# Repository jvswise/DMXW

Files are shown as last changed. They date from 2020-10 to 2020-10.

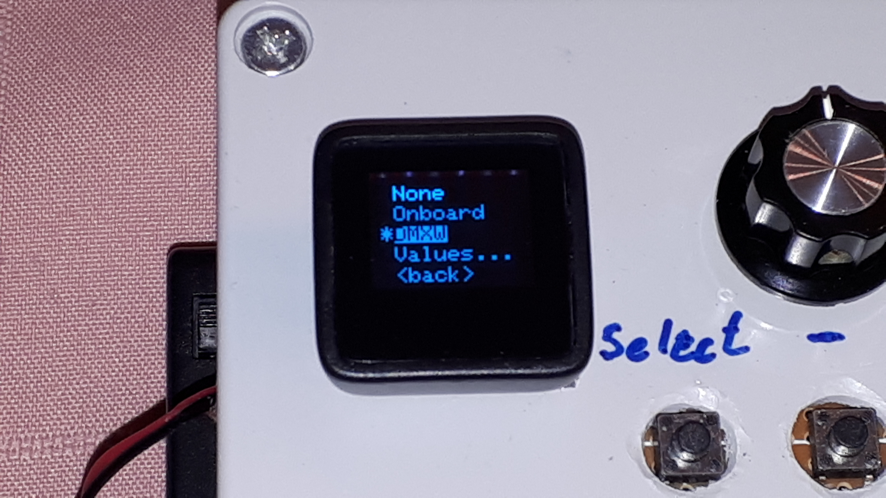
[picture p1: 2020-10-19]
Documentation/DMXW Tester Documents/Photos/Display - Outputs.jpg

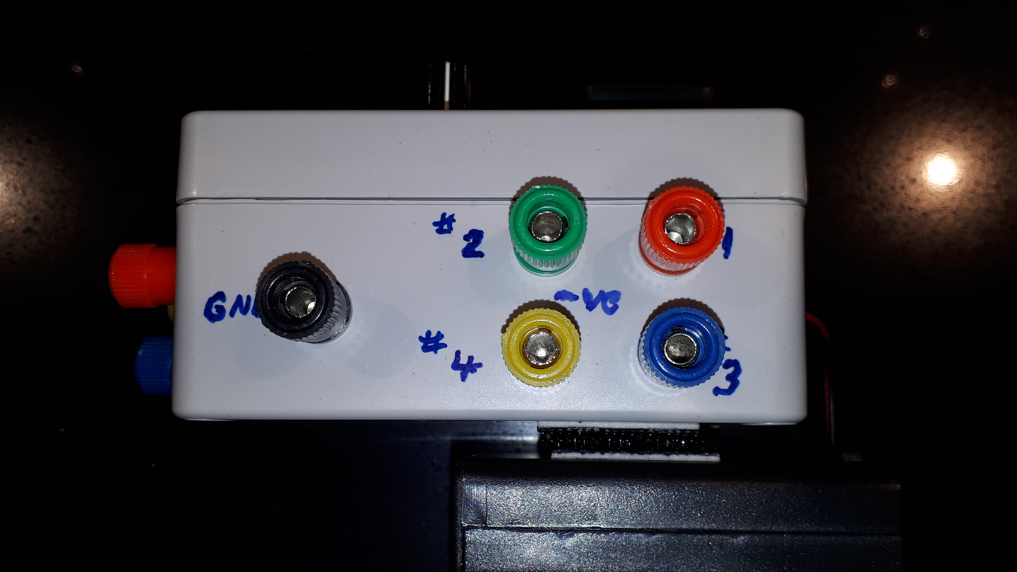
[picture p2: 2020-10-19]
Documentation/DMXW Tester Documents/Photos/Channels 1-4 connections.jpg

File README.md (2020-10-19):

# DMXW
DMX-512 wireless gateway to networked Moteino RFM69 (Arduino compatible) based slave devices suitable for running battery operated stage effects up to 300 metres from the gateway.

The gateway allows DMX-512 channels to be be redistributed to low-cost, customizable, battery-operated Moteino based slave nodes. Slaves have 4 analog (PWM) channels that can drive several amps each at 5 -12 Vdc. They have an additional two digital channels. 

There is prototype code, schematics, PCB files, and user manuals:
  - A configurable DMX-512 to DMXW gateway with optional manaul override
    controls (joystick, toggle switches, and potentiometers).
  - A generic remote slave node.
  - A specialized remote slave node for driving an LED pixel strip.
  - A test unit for either remote testing independent of a DMX-512 bus or
    for onboard testing of electronics that are to be connected to a generic
    or pixel strip node.

Folders:
  Arduino_sketches:
    - Arduino sketches for gateway, generic and remote slave nodes, and
      test unit.

  Documentation:
    - User manuals, schematics, PCB files, construction guides.

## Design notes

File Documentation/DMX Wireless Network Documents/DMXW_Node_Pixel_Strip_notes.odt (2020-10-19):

# Configuring a DMXW Node for Addressable LED Pixel Strips

The node must be running the DMXW_Node_Pixel_Strip firmware (rather than the generic DMXW_Wireless_Node firmware). This firmware only supports control of a single addressable LED strip. It is not programmed to support multiple strips, nor generic analog and digital outputs.

By default the remote node is configured to control the addressable LED strip using Moteino digital output 4 (Digital low power #1 on the J7 connector in schematic “DMXW_Driver_Board”, rev 1.1, dated 2014-07-16). To change this to a different pin, use console command “ledCtrl”

The LED strip needs to be configured on the remote node

- The console command is “led”
- LED strip length: the number of ganged tricolour LEDs (pixels)
  - 12 Vdc strips gang together three tricolour LEDs per “pixel”
  - 5 Vdc strips have one tricolour LED per pixels
- Control frequency: usually 800 Khz
- LED colour wiring order: usually GRB (?)

After changing either of the above, use console command “save” to save the configuration changes to EEPROM, and power cycle the node for the changes to take effect.

# Programming Effects:

The node defines a number of ports with pre-defined functions. Port can be mapped to arbitrary DMXW channels which can, in turn, be assigned to arbitrary DMX-512 channels.

The node's port assignments are shown in the table below.

Port # | Function
1 | Delay (in milliseconds): 0 = all LEDs off; 255 = hold current effect settings The hold setting can be used to hold an effect while other ports are changed (e.g. Manually) in advance to selecting new effect settings when Delay is taken out of hold mode. Not all effects obey delay settings in the range 1 – 254 (refer to individual effect setting in the following table)
2 | Effect: Selects the type of effect to run. To aid in manual selection via (noisy) potentiometers, each effect occupies a decade of values (refer to the following table).
3 | Parameter Arg1 | The various types of effect take varying numbers of parameters that are specified via these ports. (Refer to the following table.)
4 | Parameter Arg2
5 | Parameter Arg3
6 | Parameter Arg4
7 | Parameter Arg5
8 | Parameter Arg6
9 | Parameter Arg7

Table 1: Port Assignment Summary

The various types of effects are summarized in the following table.

Effect Name | Effect Value Range | Description | Parameters
Colour Wipe | 10 - 19 | End-to-end wipe from previous colour (black is initial colour) to newly selected colour. | Arg1 (red) Arg2 (green) Arg3 (blue) Affected by the Delay setting.
Rainbow | 20 - 29 | Wipe in a rainbow pattern. | Only affected by the Delay setting.
Rainbow Cycle | 30 - 39 | Lengthwise rolling rainbow pattern. | Only affected by the Delay setting.
Theatre Chase | 40 - 49 | Theatre marquis-style motion. | Arg1 (red) Arg2 (green) Arg3 (blue) Affected by the Delay setting.
Theatre Chase Rainbow | 50 - 59 | Theatre marquis-style motion with gradual colour change spanning the rainbow. | Only affected by the Delay setting.
Water and Embers | 60 - 69 | Undulating colour variation effect that can be used to simulate wavy waters or glowing embers. | Arg1 (red range low setting) Arg2 (green range low setting) Arg3 (blue range low setting) Arg4 (red range high setting) Arg5 (green range high setting) Arg6 (blue range high setting) Arg7 (rate of colour changes) Affected by the Delay setting. Suggested settings: For wavy waters: Red range: 0 – 0 Green range: 140 – 170 Blue range: 50 – 60 Depth: 25 Delay: 3 For glowing embers: Red range: 100 - 255 Green range: 20 – 30 Blue range: 0 – 3 Depth: 5 Delay: 3
Twinkle | 70 - 79 | Bright white twinkles on a selected background colour. | Arg1 (red) Arg2 (green) Arg3 (blue) Arg4 (min delay x 10 between twinkles) Arg5 (max delay x 10 between twinkles) Arg6 (max number of pixels that can twinkle simultaneously) Arg7 (hold time for a twinkle, in milliseconds) (The normal Delay range settings have no affect.)

Table 2: Effects Settings Summary

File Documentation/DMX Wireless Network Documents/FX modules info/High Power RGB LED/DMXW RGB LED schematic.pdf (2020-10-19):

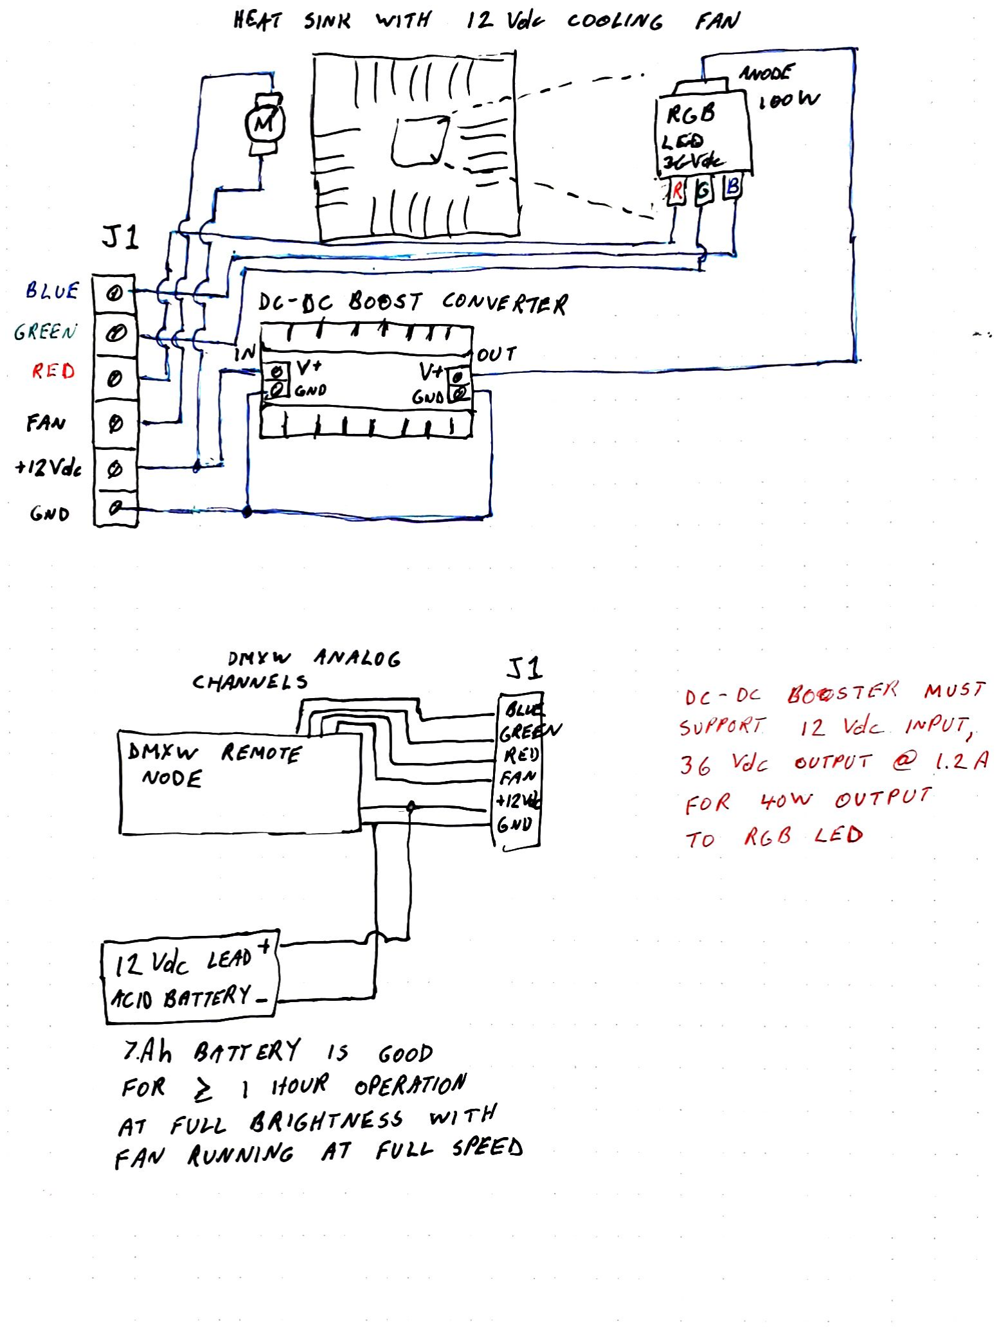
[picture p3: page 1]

HEAT SINK WITH

### 12 Volc COOLING

FAN
Illlll
WORE
11ooh
RGB
Taarde
ORG
J1
G
BLUE
DC-DC BOOST CONVERTER
GREEN
RED
YOUT
tolGND
Grote
+12Vdc Lo
GND
ANALOG
DMYW
CHANNELS
GREEN
DMXW REMOTE
NODE
RED
DC-DC BOOSTER MUST
SUPPORT 12 Voc. INPUT,
36 Volc OUTPUT @ 1.
2A
FOR 40W OUTPUT
TO RGB LED
FAN
+12 vold
GND
[ 12 volc LEAD *
ACIO BATTERY
7.Ah BATTERY IS GOOD
FOR Z 1 HOUR OPERATION

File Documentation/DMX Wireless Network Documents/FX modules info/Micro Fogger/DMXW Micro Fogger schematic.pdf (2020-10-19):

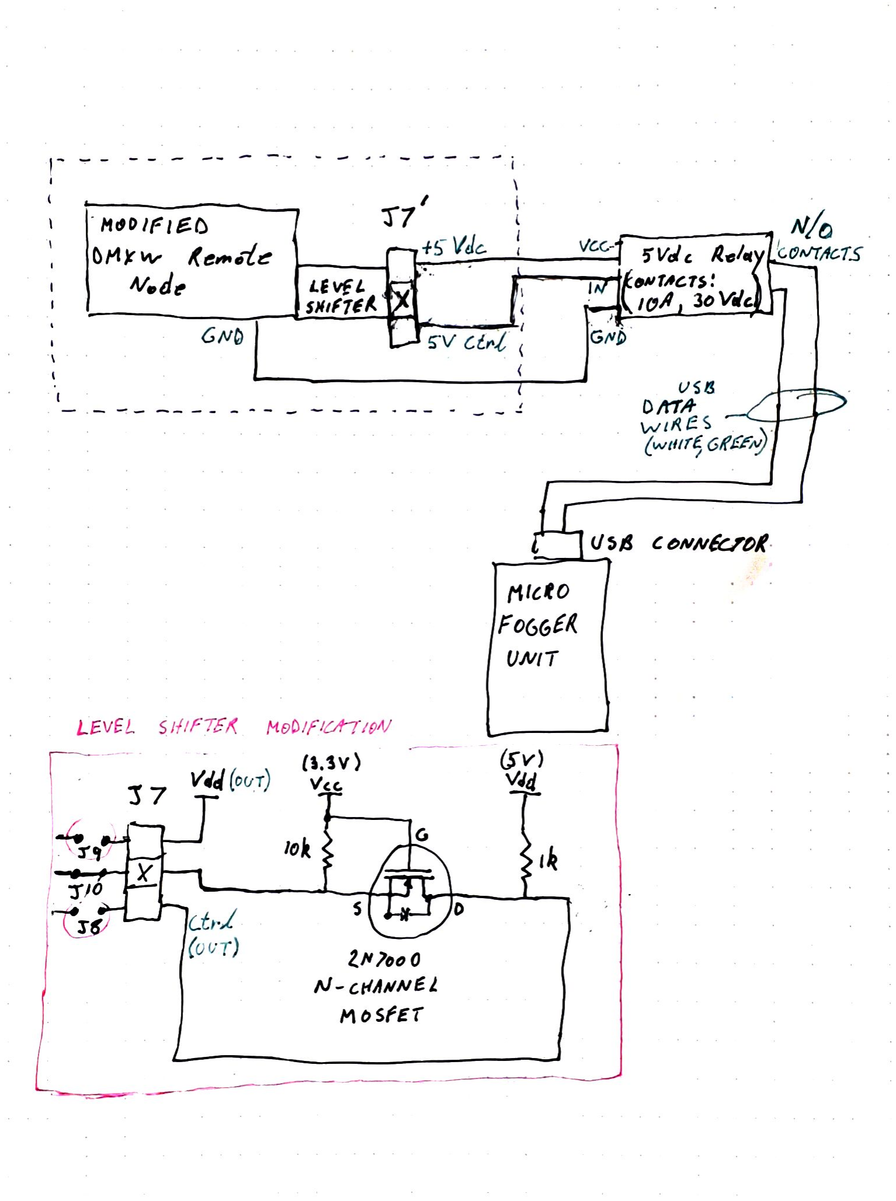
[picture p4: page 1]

MODIFIED
lomow Remote
: 57
my to kolc
LEVEL
I SHIFTER
!
- Node
Vect
- N/a
5Vdc Relay / CONTACTS
wtKONTACTS:
LIOA 30 Vich
C
GNO
GND
USB
DATA
WIRES -
(WHITE, GREEN)
USB CONNECTOR
MICRO
FOGGER
UNIT
LEVEL
SHIFTER
MODIFICATION
Irel
- VCC
Jy vold (out) (3.3v)
1
lok 3
JIÓ
st
thatod

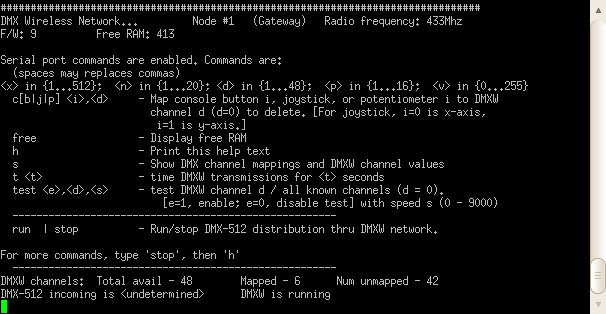
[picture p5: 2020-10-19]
Documentation/DMX Wireless Network Documents/Diagrams/Screenshots/Screenshot--dev-ttyUSB0 - PuTTY.png

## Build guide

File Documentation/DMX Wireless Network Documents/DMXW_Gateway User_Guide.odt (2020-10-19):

DMX-512 Wireless Distribution
Gateway User Guide

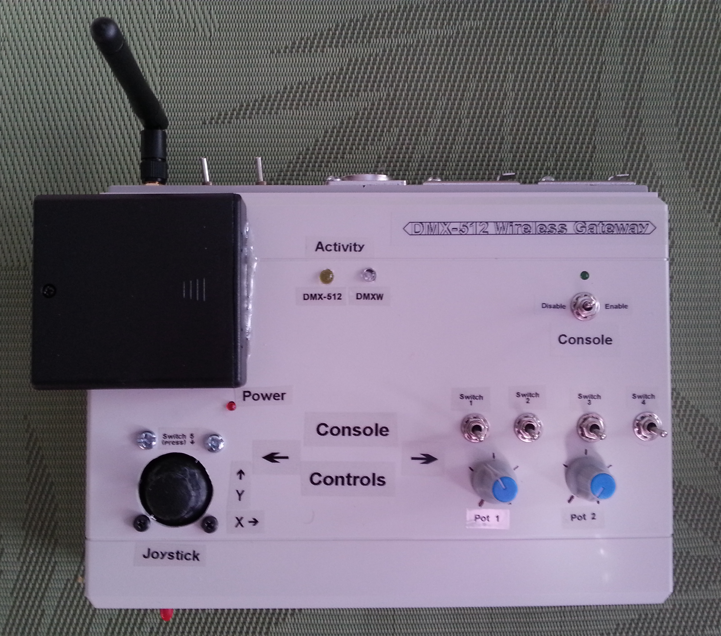
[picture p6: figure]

John van Schouwen

2014

# Introduction

## Overview

DMX-512 is an electrical and data communications standard commonly used to control stage lighting (http://en.wikipedia.org/wiki/Stage_lighting) and effects. It defines up to 512 channels of data, each intended to control a lighting fixture or an aspect of a lighting fixture (e.g. lighting fixture rotation, and lighting element brightness).[^1]

The DMX Wireless Distribution Gateway (or DMXW Gateway) has the capability to redistribute DMX-512 lighting control channels to (usually battery-powered) wireless remote DMXW receiver nodes that are connected to lighting fixtures, motors, actuators, etc.[^2] The gateway extracts up to 48 selected channels from a wired DMX-512 bus and redistributes them to up to 48 output ports located at up to 19 uniquely numbered remote DMXW nodes[^3],[^4]. Using a computer running Windows or Linux, the user can configure the DMX-512 channels to be redistributed. Various test functions are also available via this Config Port.

The gateway also houses Console Controls (switches, potentiometers, and a 2-axis joystick with push-button) that can be assigned to DMXW channels and can override the DMX-512 channels to which they are assigned.

## Features

The following are the DMXW GW features:

- Wireless redistribution (using the DMXW protocol) of up to 48 configurable DMX-512 channels onto DMXW channels.
- Support for up to 19 uniquely numbered remote DMXW wireless receiver nodes
- remote nodes may be cloned
- 433 MHz radio with range > 150 metres for DMXW distribution.
- Capability for fully mobile, standalone, manual, wireless control of up to 9 remote devices connected to one or more remote DMXW receiver nodes.
- Configurable manual console controls that can be used to override up to 9 DMXW channels:
- 4 toggle switches for on/off control (DMX-512 values 0 (off) or 255 (on))
- 2 potentiometers for dimming control
- 1 two-axis, spring-loaded joystick for dimming control
- 1 momentary contact joystick push-button for on/off control
- Console Control enable/disable switch and status indicator
- USB Configuration Port
- 9600 baud, 8-bit data, no parity, 1 stop bit
- Configuration port enable/disable switch
- Dual power option:
- 4 x AA battery pack, or
- 6 – 12 V dc, 200 mA wall adaptor using a 1/8” headphone jack (negative tip)
- DMX-512 and DMXW activity indicators
- DMX-512 bus connectivity:
- 5-pin male, 5-pin female, and 3-pin female XLR connectors for connecting to a DMX-512 bus
- unused connectors can be used for relaying the bus to additional DMX-512 devices
- DMX-512 data line polarity reversal switch (reserves the signal polarities on XLR pins 2 and 3)
- DMX-512 termination resistor (120 Ω) selector switch
- Programming Port for upgrading the gateway's firmware
- USB-to-FTDI adaptor required
- Gateway is programmed from the freely available Arduino programming environment
- Operating Mode switch selects either normal operating mode or firmware programming mode
- Freely available, open source software and development environment
- The gateway's firmware is open source Arduino code
- DMXW remote wireless receiver nodes use Arduino boards and RFM69W (433 MHz) radio modules programmed with open source Arduino code
- Assembled Arduino/radio boards (Moteino boards) can be purchased at http://www.lowpowerlab.com/shop for about $21 USD (as of March, 2014)
- Nodes will require some knowledge of electronics and construction of external circuitry in order to interface the board with output devices (such as LED’s, incandescent lamps, motors, actuators, etc.)

## Gateway Layout

Figure 1 Shows the main operating controls: the console controls and DMX activity indicators.

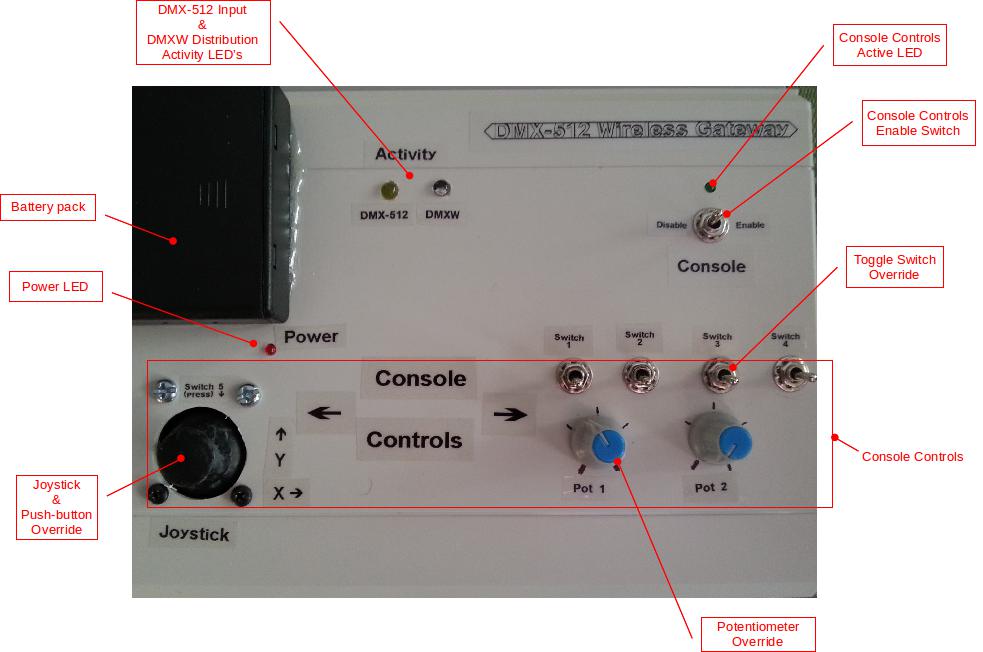
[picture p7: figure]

Figure 1: Top View

Figure 2 Shows the DMX-512 bus connectors and controls and the antenna located at the rear of the DMXW Gateway.

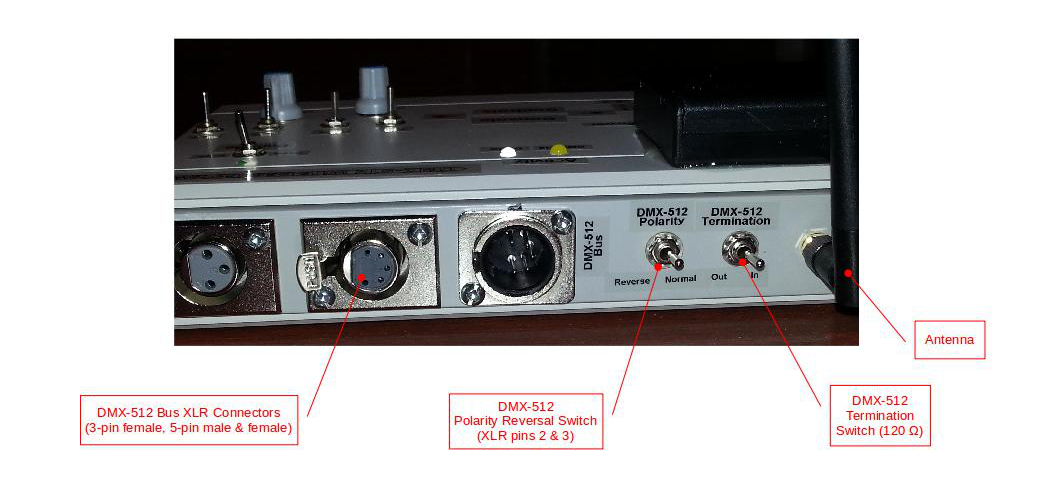
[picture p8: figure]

Figure 2: Rear View

Figure 3 Shows the DMXW Gateway's front panel containing the power switch and the configuration and programming connectors and controls.

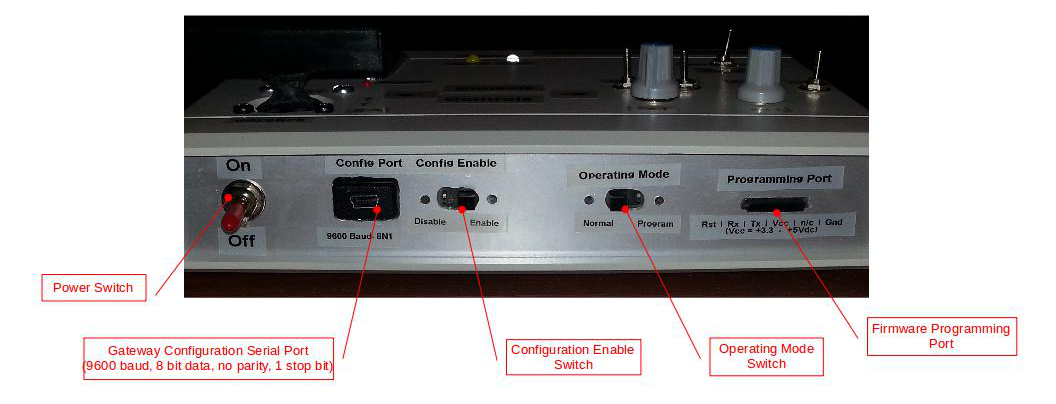
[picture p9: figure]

Figure 3: Front View

Figure 4 Shows the power sources located at the left side of the DMXW Gateway.

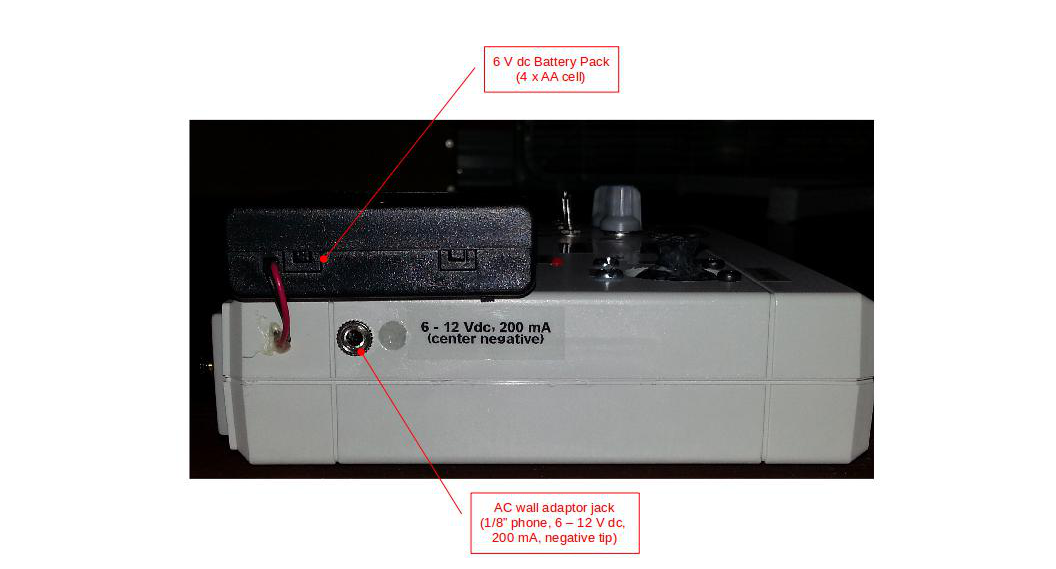
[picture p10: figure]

Figure 4: Left Side View

# Connecting the DMXW Gateway

## Connecting to a DMX-512 Bus

The DMXW Gateway can operate as either a standalone controller (using only the console controls) or connected to a DMX-512 bus for redistribution of selected channels using the DMXW wireless protocol. Referring to Figure 5, when connecting the DMXW Gateway to a DMX-512 bus, it may be connected as either an intermediate node (as shown in the figure) or as a terminating node (e.g. if DMX-512 Device #3 was disconnected).

It is often necessary for the last node on the bus to add a 120 Ω terminating resistor across the two DMX-512 data lines. If this is necessary set the DMX-512 Termination switch to the “In” position; otherwise set it to the “Out” position.

With the DMX-512 Polarity switch set to the “Normal” position, connect the DMXW Gateway to the DMX-512 bus and turn on power to the gateway. Ensure that the Power LED is lit. Make sure that the lighting desk is running DMX-512 data thru the bus. The DMX-512 Activity LED should pulsate to indicate that it is correctly receiving DMX-512 data. If the LED doesn't glow, toggle the DMX-512 Polarity switch to the “Reverse” position. If the DMX-512 Activity LED still doesn't glow, check the DMX-512 bus connections and cables, and double check that data is being transmitted by the lighting desk.

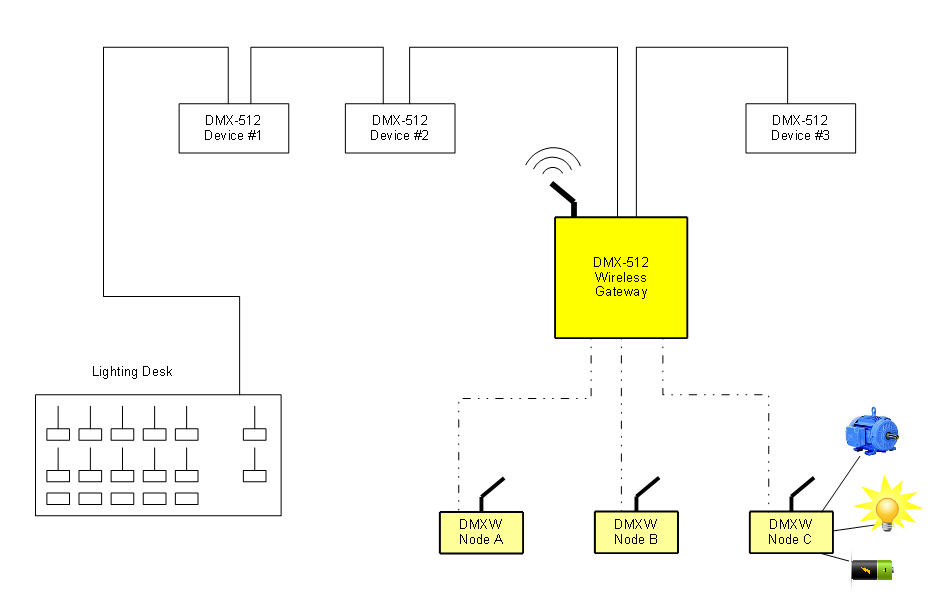
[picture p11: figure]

Figure 5: DMX-512 Network Connectivity

## Connecting a Serial Terminal to the Configuration Port

### Software Installation

Once DMX-512 activity has been confirmed, you can configure the DMX-512 channels that you wish to redistribute wirelessly. The gateway uses a CP2102 USB-to-UART (USB-to-Serial) device that provides a virtual serial COM port thru which the gateway can be configured. Before connecting a configuration terminal to the DMXW Gateway:

1. Install the CP2102 driver (both Windows and Linux versions are freely available on the Web).
2. If terminal emulator software isn't already installed on the computer, install PuTTY. (This is freely available on the Web.) PuTTY is the recommended terminal emulator.

You are now ready to connect a configuration terminal to the DMXW Gateway (see section 2.2.2 Connecting the Configuration Terminal). Once connected, you can proceed with configuring the gateway (see section 3 Configuring the DMXW Gateway).

### Connecting the Configuration Terminal

The following instructions assume that a CP2102 driver and PuTTY have been installed on the computer. (Other terminal emulator software such as minicom or HyperTerminal can be used. However, the instructions will need to be adjusted accordingly.)

1. Turn on power to the DMXW Gateway.
2. Set the Config Enable switch to the “Enable” position.
3. Determine the COM port (or, in Linux, the USB serial port number)

In Windows XP or Windows 7:

- make sure the gateway is not connected to the computer
- click the Start button, right click on My Computer, and select Properties
- in the System Properties dialogue that opens, select the Hardware tab
- click Device Manager
- scroll down to Ports (COM & LPT)
- note the ports, if any, that are already defined
- connect a mini USB cable from the computer to the gateway Config Port
- note which COM port gets added to the list

e.g. “Silicon Labs CP2102x USB to UART Bridge (COM7)”

- note the configuration port's COM port (e.g. COM7)
4. Run PuTTY:

First time use:

- Select the “Serial” radio button in the “Connection type:” field.
- In the “Serial line” field, enter the DMXW Gateway's COM port (e.g. COM7)
- In the “Speed” field, enter 9600.
- In the “Category:” pane on the left side, click “Terminal”.
- Select the “Force on” radio button in the “Local echo:” field.
- In the “Category:” pane, click “Serial” (under the “Connection” category).
- The “Serial line to connect to” and “Speed (baud)” fields should already be set correctly (e.g. COM7 and 9600)
- In the “Data bits” field, enter 8.
- In the “Stop bits” field, enter 1.
- In the “Parity” field, select “None” from the drop-down list.
- In the “Flow control” field, select “None” from the drop-down list.
- In the “Category:” pane, click “Session”.
- In the “Saved Sessions” field, enter a name that makes sense to you (e.g. “DMXW Gateway”)
- Click the “Save” button to save these settings for future use.
- Finally, click the “Open” button to open a terminal connected to the DMXW Gateway.

Subsequent use:

- In the “Save Sessions” list, double click on the session you saved for the DMXW Gateway.
5. If nothing is immediately displayed in the terminal window, toggle the Config Enable to the “Disable” position and then back to the “Enable” position. If still nothing is seen, toggle the power to the DMXW Gateway off and on again. If still nothing is seen, then {* ?? Houston we have a problem. *}

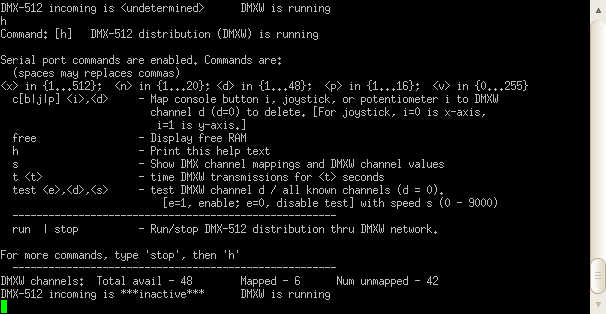
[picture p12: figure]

6. Enter h to get a list of commands available in the current DMXW distribution mode. When the gateway is first powered on, the default distribution mode is running and the help screen appears as in the figure below. (In this distribution mode, you will notice that the DMXW Activity LED pulsates.) While DMXW channels are being broadcast, there is a limited number of commands available as most commands interfere with the channel data transmission timing.

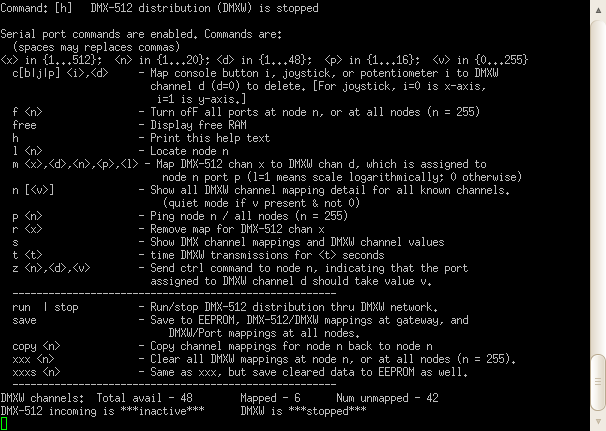
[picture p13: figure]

If you enter the stop command, the mode will switch to DMXW distribution stopped and the DMXW Activity LED will turn off. When you enter h again, the help screen will appear as in the figure below. Entering run will cause the gateway distribution mode to switch back to running. During configuration, most of the commands will be entered while DMXW distribution is stopped.

# Configuring the DMXW Gateway

Whether you choose to use the DMXW Gateway as a standalone controller or for wireless redistribution of DMX-512 channels, you will need to configure mappings from DMX-512 channels to DMXW channels and DMXW channels to output ports on DMXW nodes.

Figure 6 illustrates how DMX-512 channels can map to DMXW channels which then map to output ports at various DMXW remote nodes. The DMXW Gateway ultimately provides the mappings from DMX-512 channels to the remote nodes' output ports. Using the configuration terminal, from 1 – 48 DMX-512 channels are each arbitrarily mapped to a unique DMXW channel and each DMXW channel is mapped to a DMXW remote node number and one of that node's port numbers. As an example from the figure, DMX-512 channel #505 could be mapped to DMXW channel #6, which is mapped to port #15 on DMXW Node #2, which in turn may be connected to a motor.

## Entering Configuration Terminal Commands

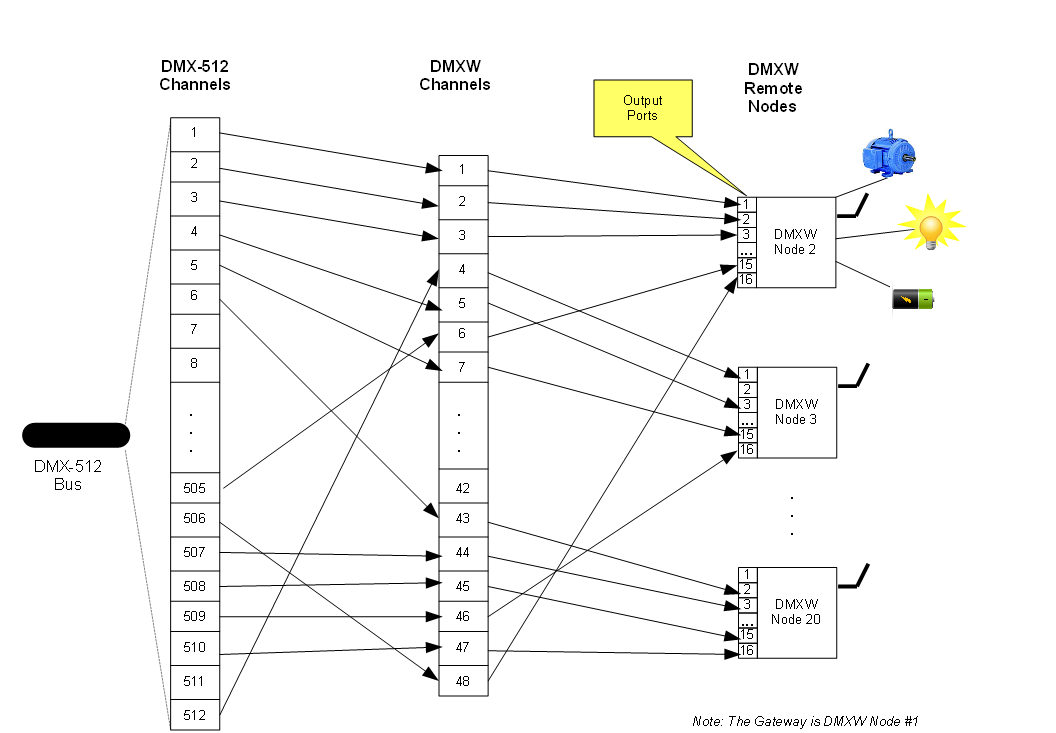
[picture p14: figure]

Figure 6: DMXW Channel Mapping

Configuration terminal commands use a loose syntax: it is not necessary to have a space immediately following the command name; and, command parameters may be separated by either commas or spaces and extra spaces between parameters are ignored. For example, the channel mapping command (m) has the following stated syntax:

m <x>,<d>,<n>,<p>,<l>

The following entered commands would be equivalent:

m 505,6,2,15,0

m505 6 2 15 0

m 505, 6 2,15 0

The examples in this section use the first form.

## Disabling the Configuration Terminal

At times it may be convenient to leave the configuration terminal connected to the DMXW Gateway while the DMXW distribution is running. Yet, you may wish to safeguard against commands—and their potentially negative consequences—being activated accidentally at the terminal. To provide this measure of safety, slide the Config Enable switch to the “Disable” position. A short informational message will appear at the terminal and no commands will be accepted until the switch is moved back to the “Enable” position.

## About DMX Distribution Modes

When the DMXW Gateway is first powered on, DMXW distribution will start actively running. The gateway DMXW distribution is said to be in running mode. While in this mode the DMXW Activity LED pulsates and the configuration terminal help screen (enter the h command) will reflect this as shown at the bottom right of Figure 7.

By entering the stop command in the configuration terminal, DMXW distribution will stop. The gateway DMXW distribution is then said to be in the stopped mode. While in this mode the DMXW Activity LED will remain off and the configuration terminal help screen will reflect the new mode as shown at the bottom right of Figure 8. Entering the run command will start DMXW distribution running again.

A number of configuration terminal commands interfere with DMXW distribution. So fewer commands are available while DMXW distribution is running. One additional command, test, is only available in running mode since it runs a test of all DMXW channels that are mapped at the gateway.


Figure 7: Configuration Terminal Help Display While DMXW Distribution is in "Running" Mode

Figure 8: Configuration Terminal Help Screen while DMXW Distribution is in "Stopped" Mode

## Mapping DMX-512 Channels to DMXW Channels

1. At any time, enter h for help with configuration terminal commands, to see the current DMX-512 activity and DMXW distribution status, and see a summary of the number of DMXW channels that have been mapped and remain available.
2. Enter stop at the configuration terminal to ensure DMXW distribution is stopped.
3. To map DMX-512 channel #505 to DMXW channel #6 which is to get distributed to port #15 at DMXW remote node #2 (see Figure 6), enter the following command:[^5]

m 505, 6, 2, 15, 0

4. If port 15 is a digital output (on/off) port, the “0” in the command is fine. However, if the port is an analog output port (responding in some proportion to channel data values 0 – 255), you need to determine whether the device connected to that port has a linear or logarithmic response to the channel data values. For example, people perceive a doubling of light output as less than double; it's perceived as a logarithmic increase relative to actual output. If an uncompensated light source is connected to an output port, then using the previous example, enter the following command:

m 505, 6, 2, 15, 1

In this way, output port 15 will have a logarithmic response to the data values piped thru DMX-512 channel #505. It will also have a logarithmic response to a console control potentiometer or joystick axis if one is mapped to DMXW channel #6.

5. If a light source connected to port 15 is compensated (such that a change in channel data value from, say, 10 – 20, is perceived as a doubling of light intensity), then the command in step (3) is more appropriate.
6. To confirm the current set of mappings, enter s to show the complete list of mappings, including which (if any) console controls are mapped to DMXW channels (refer to section 3.5 Mapping Console Controls to DMXW Channels).
7. Repeat steps (3) thru (6) as desired.
8. If it is necessary to remove individual mappings, enter:

r <DMX-512 channel #>

## Mapping Console Controls to DMXW Channels

1. At any time, enter h for help with configuration terminal commands, to see the current DMX-512 activity and DMXW distribution status, and see a summary of the number of DMXW channels that have been mapped and remain available.
2. Console controls can be mapped to DMXW channels while DMXW distribution is either stopped or running.
3. The syntax for mapping a console control is:

c<b | j | p> <i>,<d>

where: <i> is the control # and <d> (in the range 1 – 48) is the DMXW channel # to which the control is to be mapped (or 0 to remove the mapping).

There should be no space between c and the next character.

There are a total of 9 individual console controls that can be mapped to any DMXW channel.

There are 5 on/off buttons or switches: buttons (switches) 1 – 4 are toggle switches; and, button 5 is the momentary contact switch located on the joystick. To map one of these, enter:

cb <i>,<d>

where: <i> is in the range 1 – 5

There are 2 potentiometers. To map one of these, enter:

cp <i>,<d>

where: <i> is 1 or 2

There are 2 joystick axes (each equivalent to a spring-loaded potentiometer). To map one of these, enter:

cj <i>,<d>

where: <i> is 0 (for the left-to-right X axis) or 1 (for the up-to-down Y axis)

4. As an example, to map the joystick Y axis to DMXW channel #6 (DMX-512 channel #505 from the example in the previous section), enter:

cj 1,6

5. To confirm the mapping, enter:

s

6. Repeat steps (3) - (5) as desired.
7. Be careful not to map more than one control to the same DMXW channel. The behaviour of the controls will be unpredictable. You can execute the next step if you need to remove a mapping.[^6]
8. To remove a mapping, use the c command with a “0” for the DMXW channel #. For example, to remove the mapping that was added in step (4), enter:

cj 1,0

## Saving and Clearing Configuration Data

Changes to DMX-512 and console control mappings are lost if the DMXW Gateway or a remote DMXW node loses power unless the changes are saved. While DMXW distribution is stopped, channel mapping changes can be saved by entering the following command at the configuration terminal:

save

This will cause the gateway and all mapped remote nodes to save their mappings so that they will survive power losses.

Channel mappings for a node can be wiped out by entering one of the following commands:

xxx <DMXW remote node #>

- This will clear all channel mappings for the specified remote node, both at the node and at the gateway. The change, however, is not saved; if the node or gateway power is toggled off and on, the mappings will reappear and there may be a mapping inconsistency between the node and gateway. As long as there are no mappings defined at the node, a save command will save the changes at the gateway, but not at the node. If you wish to clear the node's mappings and have the change saved at the node, use the xxxs command. If you wish to clear the node's mappings but add at least one new mapping, a subsequent save will cause the new mapping to be saved at the node (and, of course, at the gateway).

xxx 255

- This will clear the mapping for all remote nodes, both at the nodes and at the gateway. Again, the changes are not saved and mapping inconsistencies could occur if a device loses power. The same cautions as above apply regarding subsequent save commands.

xxxs <DMXW remote node #>

- This will both clear all channel mappings for the specified remote node (both at the node and at the gateway) and save those changes (at both the node and gateway).

xxxs 255

- This will clear all channel mappings for all remote nodes and save the changes, both at the nodes and at the gateway.

## Copying Channel Mappings from Gateway to Remote Node

In the event that the channel mappings at a remote node become inconsistent with the gateway, you can either clear all of the mappings or copy back the mappings that are known by the gateway back to the remote node. If you have multiple remote nodes that have the same node #, this mechanism can be used to clone the node. To copy the channel mappings for a node, enter the following command:

copy <n>

where: <n> is the node # (in the range 2 – 20)

To make the changes permanent, save the changes by entering:

save

## Miscellaneous Commands

l <n> where: <n> is a node # (in the range 2 – 20, or 255)

- Remote DMXW nodes typically have an LED intended for locating and distinguishing between multiple nodes. This command is only available while DMXW distribution is stopped. It will activate a visible indicator (usually a blinking LED) at the node until it is instructed to turn off (refer to the f command below).
- When <n> = 255, all nodes will blink. This can be useful for determining whether or not a node is recognized and properly programmed.

f <n> where: <n> is a node # (in the range 2 – 20, or 255)

- This command instructs the specified remote DMXW node (or all remote nodes) to turn off all of their output ports. It can be used to quiet down a located node, or to turn off outputs that have been, for whatever reason, left on.

p <n> where: <n> is a node # (in the range 2 – 20, or 255)

- This command “pings” a remote DMXW node (or all remote nodes), instructing it (them) to confirm its (their) presence on the DMXW wireless network.
- If you have cloned nodes on the network (i.e. multiple nodes with the same node #), they are unlikely to respond correctly.

n

- This command queries remote DMXW nodes to report their details on each DMXW channel mapping that is known to the DMXW Gateway. The gateway queries each individual channel mapping one at-a-time.

z <n>,<d>,<v>

where: <n> is a node # (in the range 2 – 20)

<d> is a DMXW channel # (in the range 1 – 48)

<v> is a DMX-512 data value (in the range 0 – 255)

- This command instructs node # <n> to set the value of the output port that's mapped to DMXW channel # <d> to value <v>.
- This command can be used for testing a channel mapping without the need to use either the console controls or have an active DMX-512 bus feed.

test <e>,<d>,<s>

where: <e> is 1 (to start the test) or 0 (to abort the test)

<d> is a DMXW channel # (in the range 1 – 48) or
0 (to test all 48 DMXW channels)

<s> is a relative test speed control value (in the range 0 – 9000)

- This command runs a test sequence on the specified DMXW channel. It cycles thru the data values 0 – 255, repeating the cycle for 10 iterations (unless aborted).
- If <d> = 0, each of the 48 DMXW channels is tested in turn (from channel #1 thru to #48) during each of the 10 iterations.
- To abort the test, enter: test 0
- You may have to repeat the command two or three times before the test stops.
- This command can be used, for example, to quickly check that a node (or nodes) is powered up and operating correctly. It does not require the use of gateway console controls or an active DMX-512 bus feed.

## Firmware Developer Commands

The following commands are typically only useful to firmware developers:[^7]

free

t <t>

# Operating the DMXW Gateway

The DMX-512 Wireless Gateway (or DMXW Gateway) can be used in two main operating modes as dictated by the position of the Operating Mode switch on the gateway's front panel:

- Normal – the normal mode of operation (described in this section).
- Program – the mode used for upgrading the gateway's firmware (refer to section 6 Upgrading the DMXW Gateway Firmware).

While in normal operating mode, the gateway can be used in two ways:

- Standalone operation:

In this mode the DMXW Gateway need not be wired to a DMX-512 bus. Once appropriate channel mappings have been configured, console controls on the gateway have been mapped to DMXW channels, and the console controls enabled, the console controls on the gateway can be used for manual control of up to 9 output ports located on one or more remote DMXW nodes. When the gateway is running under battery power, this provides for a very mobile means of manual control. In this mode the Console switch on the gateway's top console panel should be set to the “Enable” position and the LED above the switch should be lit.

- DMX-512 redistribution operation:

In this mode the DMXW Gateway needs to be wired to a DMX-512 bus. Once appropriate channel mappings have been configured, a DMX-512 lighting desk can control up to 48 output ports located on one or more remote DMXW nodes. Console controls on the gateway may also be mapped to up to 9 DMXW channels and can enabled at any time for manual override of their corresponding DMX-512 channels. To enable manual override, the Console switch should be set to “Enable”. The LED above the switch is lit whenever the console controls are enabled for manual override.

## Setting Up

1. Before using the DMXW Gateway for normal operation, it must first be configured with at least one channel mapping from a DMX-512 channel to a DMXW channel to an output port on a remote DMXW node. Refer to section 3 Configuring the DMXW Gateway.
2. If you will be using the DMXW Gateway for DMX-512 redistribution, ensure that the gateway is connected correctly to the DMX-512 bus. Refer to section 2.1 Connecting to a DMX-512 Bus.
3. With the DMXW Gateway configured, ensure that the Operating Mode front panel switch is set to the “Normal” position.
4. You may wish to keep a configuration terminal connected to the DMXW Gateway. If so, you may decide at any time to enable or disable terminal commands as described in section 3.2 Disabling the Configuration Terminal.
5. Power up the DMXW Gateway. The DMXW Activity LED should start pulsating. If not, and a configuration terminal is connected, enter the run command to start DMXW distribution running.
6. If you are redistributing DMX-512 channels, ensure that there is an active data feed coming from the DMX-512 data source (such as a lighting control console). Confirm the feed is active by noting that the DMX-512 Activity LED is pulsating.
7. For standalone operation, or if manual control is otherwise desired, ensure that the Console switch is set to the “Enable” position; the LED above the switch will light up. Otherwise, ensure that it is set to the “Disable” position (and the LED will be off).
8. It is a good idea to confirm that all DMX-512 channels and console controls are operating as expected prior to commencing normal operation.

# Configuring and Programming Remote DMXW Receiver Nodes

A DMXW remote wireless receiver node can use any underlying computer platform chosen by its designer. It only needs to ensure that it uses an RFM68W 433 MHz radio and that it conforms to the DMXW protocol. This section only applies to DMXW remote wireless receiver nodes that are implemented using one of the Moteino micro-controller boards (http://www.lowpowerlab.com/shop).

To configure or program a Moteino based remote DMXW node, you will need:

- The Arduino IDE (as is used for upgrading the DMXW Gateway firmware)
- If the underlying Moteino board, or the node on whole, lacks a built-in USB port, a USB-to-FTDI adaptor is needed.

To program a Moteino based remote DMXW node, you will also need a copy of the freely available “DMXW Node” Arduino source code.

Connecting to the node will depend on whether or not the board has a built-in USB port (requiring a USB-to-FTDI adaptor versus requiring just a mini USB cable between node and computer). Once connected, however, the programming steps are the same.

Programming (or upgrading the firmware of) a remote DMXW node involves the same process as for the gateway. (Refer to section 6 Upgrading the DMXW Gateway Firmware.) When modifying the firmware, it is recommended that you increment the firmware version number. This will ensure that the device erases configuration data (such as the DMXW channel mappings) from its EEPROM the next time it is powered up. This is especially important if the structure of the data stored in EEPROM is changed.

Configuring a Moteino based DMXW node can be done using either terminal emulator software (such as PuTTY) or directly within the Arduino IDE by opening the IDE's Serial Monitor while connected to the node. The icon for the monitor is located near the top right of the IDE window. When you click on the icon, the DMXW node is reset and an IDE terminal window opens. Once connected, you should see a banner followed by some help text. The banner identifies the Moteino as a DMXW node running at 433 MHz, the firmware version number, and the DMXW node number (Node ID). If you need to modify the node number, enter the following command in the command line at the top of the monitor window:

nodeid <new node number>

where: <new node number> is in the range 2 – 20

You should ensure that all remote DMXW nodes are uniquely numbered unless you plan on cloning nodes. If you do plan to clone nodes, ensure that every node with the same node number has the same data copied to it. (Refer to the copy command in section 3.7 Copying Channel Mappings from Gateway to Remote Node.)

The other command you will likely want to use at some point is the s (show) command that lists information about DMXW channel mappings as known to the node.

## Powering a Remote DMXW Receiver Node

A DMXW Receiver Node is typically connected to, and controls, devices that have large electrical power needs relative to the Moteino. The Moteino can be fed with 3.3 – 12 Vdc and, itself, uses very little power; it can actually run on coin cell batteries for months. In order to protect the sensitive Moteino board, it is recommended that careful thought be applied to ensure that any Moteino input or output port which connects to logic, switching, or amplifying circuity running at higher voltages is electrically isolated from the Moteino ports—e.g. using opto-isolators. If the Moteino directly controls an electo-mechanical relay, ensure that a diode is placed across the relay's energizing coil, as a very large reverse voltage spike is possible when a relay is de-energized. In cases where 120 Vac mains power is needed for the controlled devices, it is strongly recommended that you: (1) find help from a qualified person; and, (2) install electrical isolation mechanisms between the mains power circuitry and the low voltage circuitry.

# Upgrading the DMXW Gateway Firmware

The DMXW Gateway's firmware can be updated by powering it on and setting the Operating Mode switch to the “Program” position. You will need to have:

- a computer that is running the freely available Arduino Integrated Development Environment (IDE)
- a USB-to-FTDI connector, and
- the DMXW Gateway source code
  The gateway uses the equivalent of an Arduino UNO board. Go to the Arduino web site (http://www.arduino.cc) to acquire the IDE and for instructions on programming an Arduino board.
  In the Arduino IDE, be sure to set Tools > Board > Arduino Uno

[^1] Each DMX-512 channel consists of a stream of data, each data value in the range 0 – 255 (inclusive).
[^2] A remote receiver node could, however, use 120 Vac mains power for, e.g., situations where DMX-512 is awkward or prohibitve while mains power is accessible and needed for the device(s) being controlled.
[^3] It is possible to clone nodes, thereby increasing the total number of DMXW remote nodes. A cloned node will share the remote DMXW node number and channel mapping configuration.
[^4] The gateway and remote nodes communicate using a simple bidirectional protocol—the DMX Wireless (DMXW) protocol.
[^5] In the future, this command will likely be split into multiple commands for mapping DMX-512 channel numbers to DMXW channel numbers, and for mapping DMXW channel numbers to node number, port number pairs. This will allow the DMXW channels to be configured prior to having determined which DMX-512 channels are to be used. It will also allow DMXW channels to be reassigned to different DMX-512 channels without requiring full knowledge of the node and port numbers—with, say, function or role names assigned to the DMXW channels.
[^6] This is only because there is a bug in the code. (To be corrected.)
[^7] These are to be removed from the regular menu. TBD: create a separate debug help command.

DMX-512 Wireless Distribution Gateway User Guide 2014-04-11

25 of 27 J. van Schouwen

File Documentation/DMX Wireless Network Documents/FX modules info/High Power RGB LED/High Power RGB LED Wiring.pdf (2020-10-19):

2020-03-16 | J. van Schouwen | 1

# Wiring for DMXW High Power LED

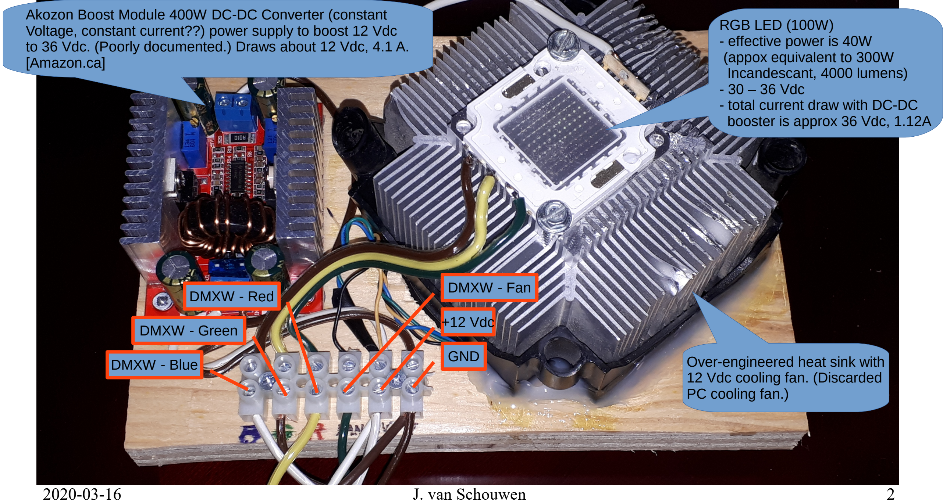
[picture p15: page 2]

RGB LED (100W)
- effective power is 40W
(appox equivalent to 300W
Incandescant, 4000 lumens)
- 30 – 36 Vdc
- total current draw with DC-DC booster is approx 36 Vdc, 1.12A

Over-engineered heat sink with 12 Vdc cooling fan. (Discarded PC cooling fan.)

Akozon Boost Module 400W DC-DC Converter (constant Voltage, constant current??) power supply to boost 12 Vdc to 36 Vdc. (Poorly documented.) Draws about 12 Vdc, 4.1 A. [Amazon.ca]

GND

+12 Vdc

DMXW - Fan DMXW - Red

DMXW - Green

DMXW - Blue

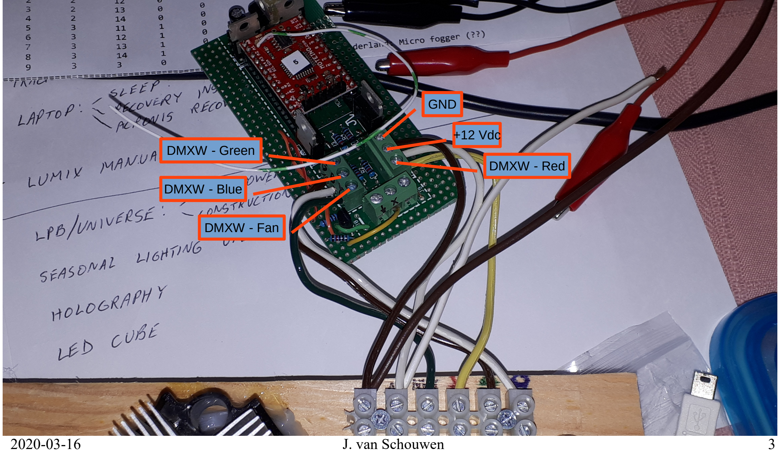
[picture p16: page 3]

GND

+12 Vdc

DMXW - Fan

DMXW - Red

DMXW - Green

DMXW - Blue

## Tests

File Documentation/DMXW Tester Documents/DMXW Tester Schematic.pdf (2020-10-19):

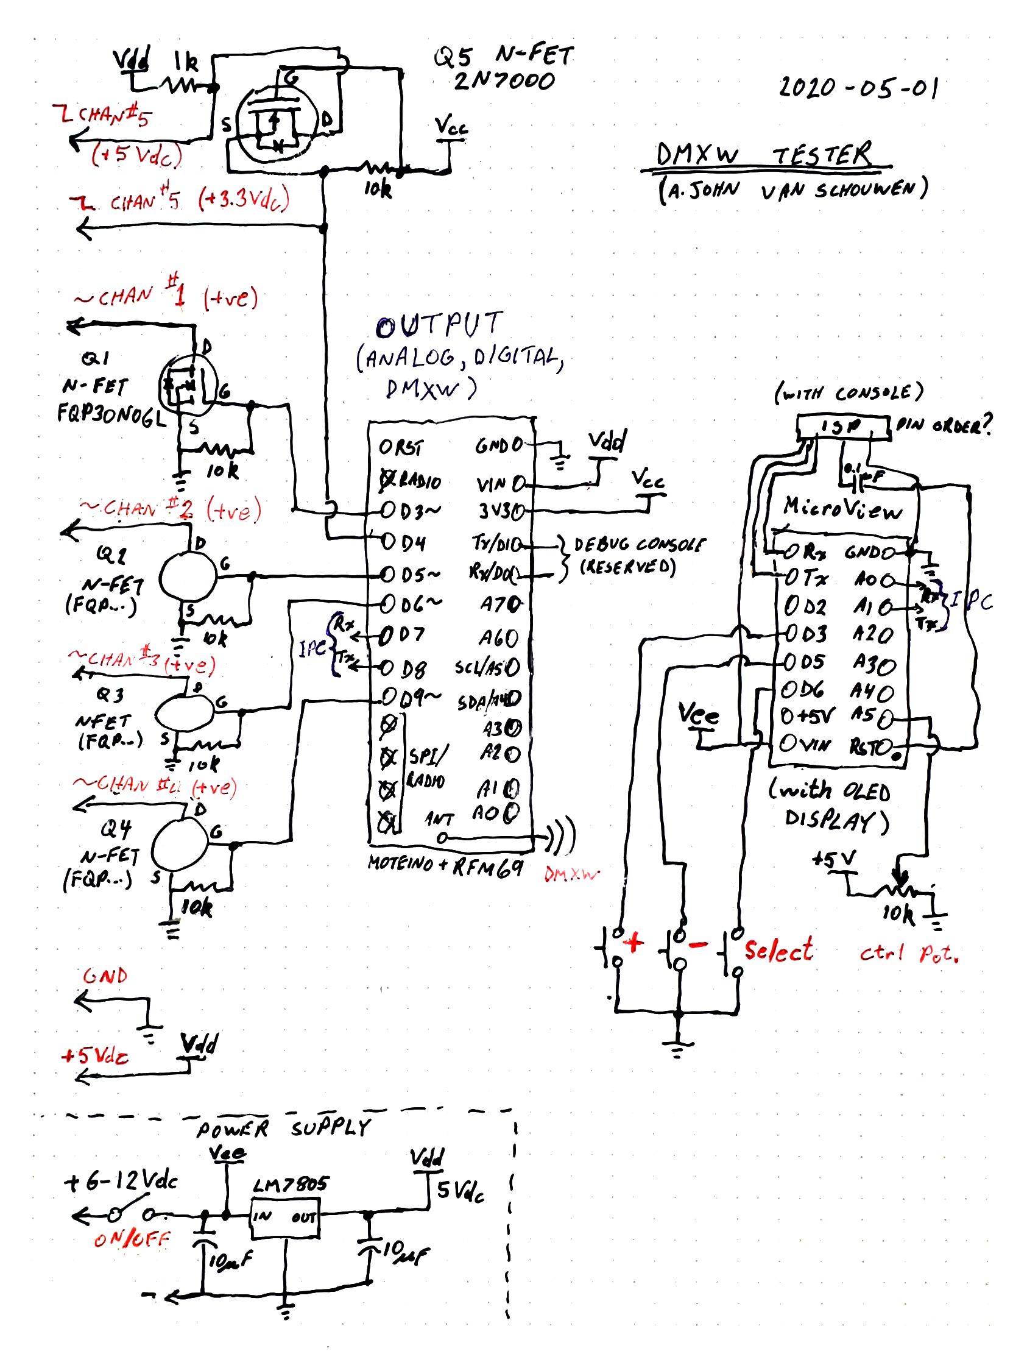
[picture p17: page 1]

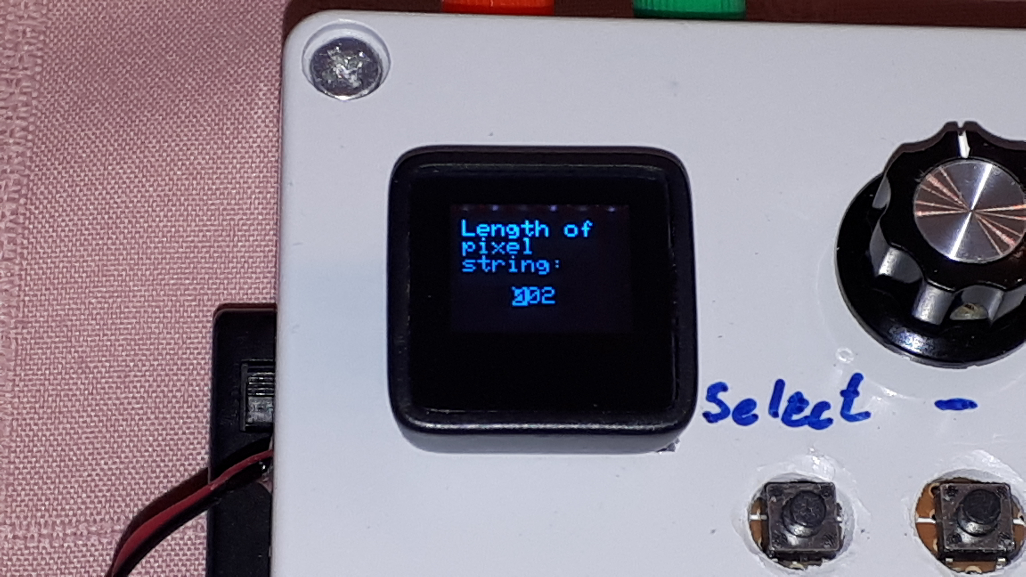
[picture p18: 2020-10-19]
Documentation/DMXW Tester Documents/Photos/Display - Pixel len.jpg

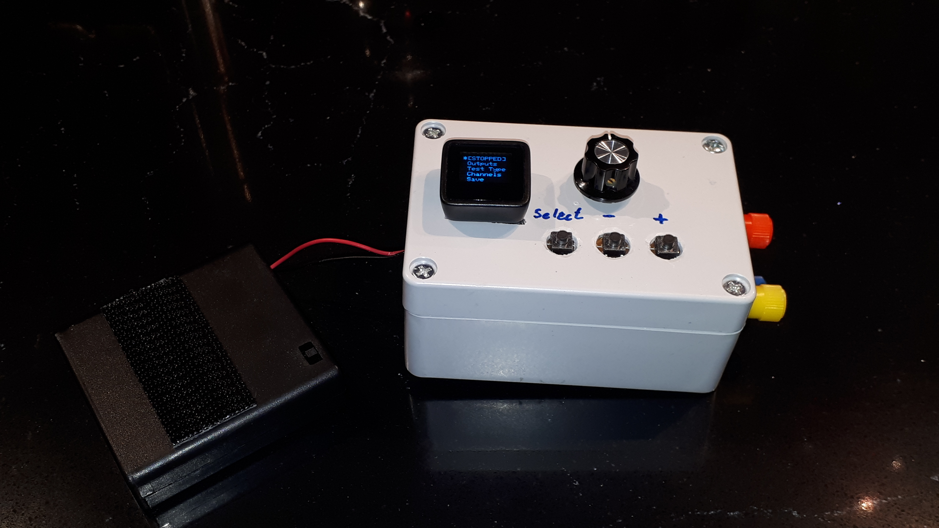
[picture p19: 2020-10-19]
Documentation/DMXW Tester Documents/Photos/Top panel (battery pack detached).jpg

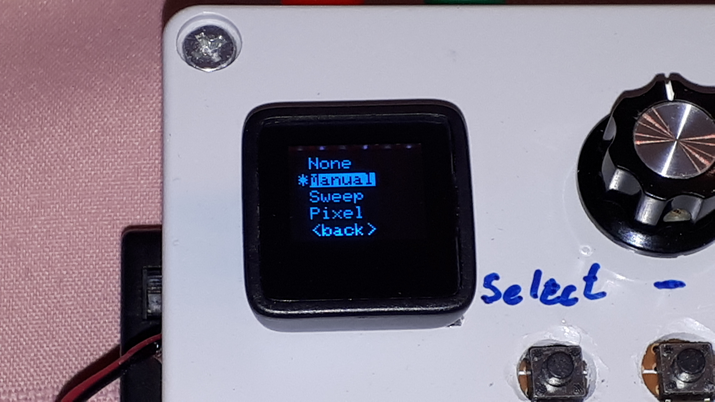
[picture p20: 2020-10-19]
Documentation/DMXW Tester Documents/Photos/Display - Test Type.jpg

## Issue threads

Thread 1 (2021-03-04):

RFM69_DMX.h

yeeliz, 2021-03-04:
Please can you tell me where I download this file (RFM69_DMX.h), it is not included in the zip.

jvswise, 2021-03-05:
I've uploaded my modified version of the RFM69 library. Check out the latest tag, 2021-03-04_Release_3_initial.

jvswise, 2021-03-05:
I’ve uploaded my modified version of the RFM69 library.

Sent from Mail for Windows 10

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

Closed 2021-03-05.

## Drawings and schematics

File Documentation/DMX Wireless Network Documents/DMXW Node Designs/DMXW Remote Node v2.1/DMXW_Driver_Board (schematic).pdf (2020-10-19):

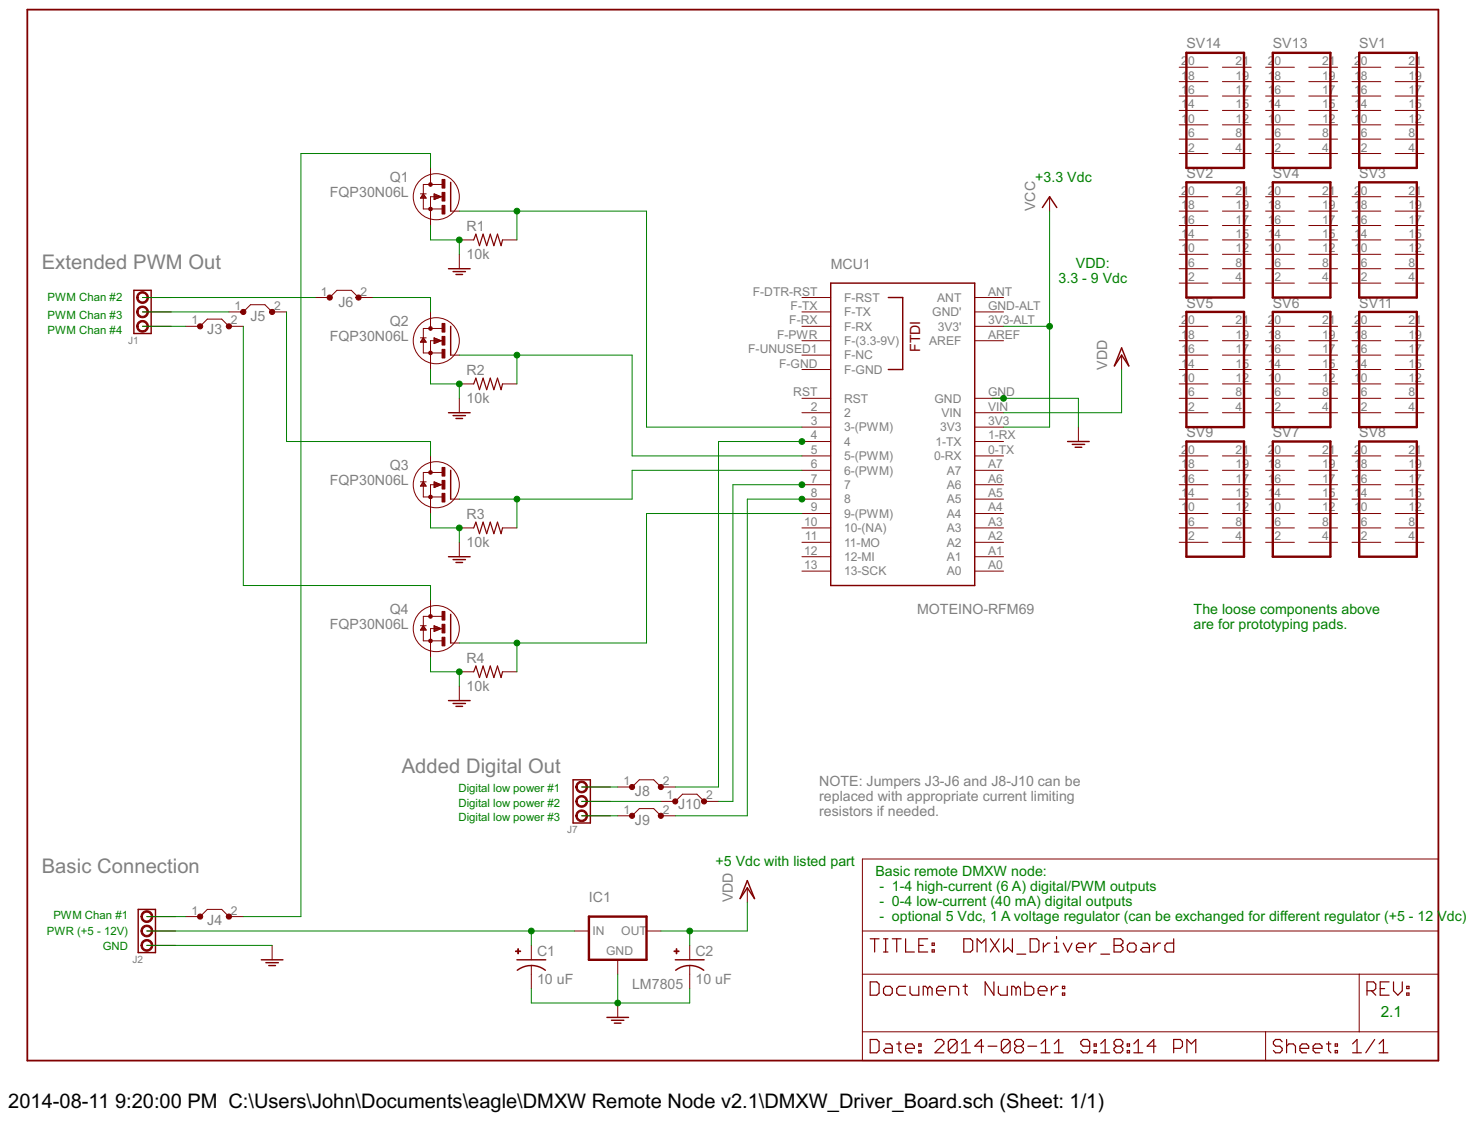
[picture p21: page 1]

PWM Chan #4 PWM Chan #3 PWM Chan #2

RST RST 2 3-(PWM) 3 4 7 8 11-MO 13-SCK | 3V3 1-TX 0-RX

3V3 VIN

The loose components above
are for prototyping pads.

NOTE: Jumpers J3-J6 and J8-J10 can be
replaced with appropriate current limiting
resistors if needed.

Digital low power #3 Digital low power #2 Digital low power #1

Basic remote DMXW node: - 1-4 high-current (6 A) digital/PWM outputs

- 0-4 low-current (40 mA) digital outputs

2014-08-11 9:20:00 PM C:\Users\John\Documents\eagle\DMXW Remote Node v2.1\DMXW_Driver_Board.sch (Sheet: 1/1)

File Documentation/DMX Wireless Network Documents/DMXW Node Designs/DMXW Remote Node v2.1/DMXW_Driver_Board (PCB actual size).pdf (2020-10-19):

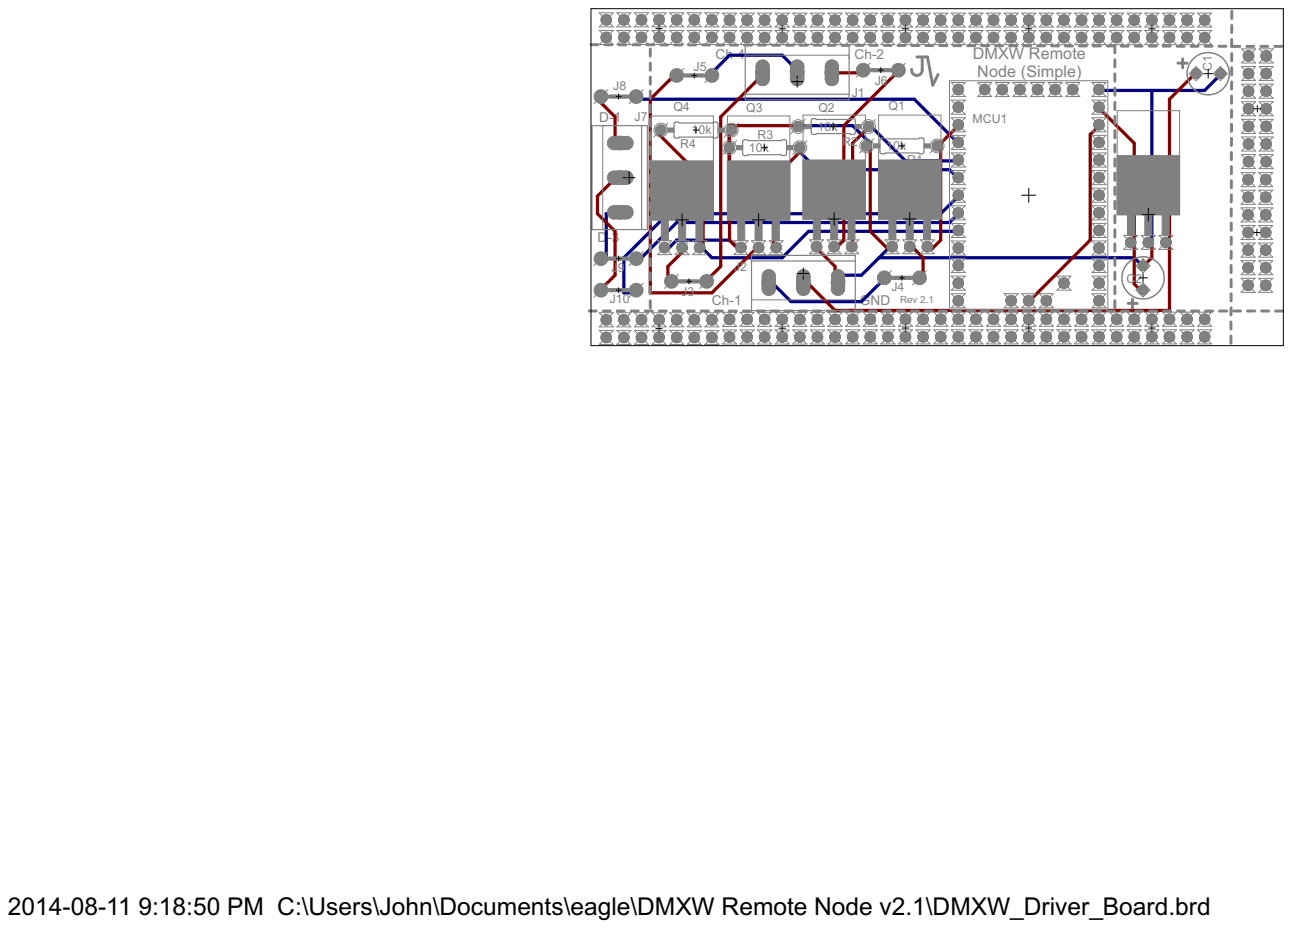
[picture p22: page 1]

DMXW Remote Node (Simple)

2014-08-11 9:18:50 PM C:\Users\John\Documents\eagle\DMXW Remote Node v2.1\DMXW_Driver_Board.brd

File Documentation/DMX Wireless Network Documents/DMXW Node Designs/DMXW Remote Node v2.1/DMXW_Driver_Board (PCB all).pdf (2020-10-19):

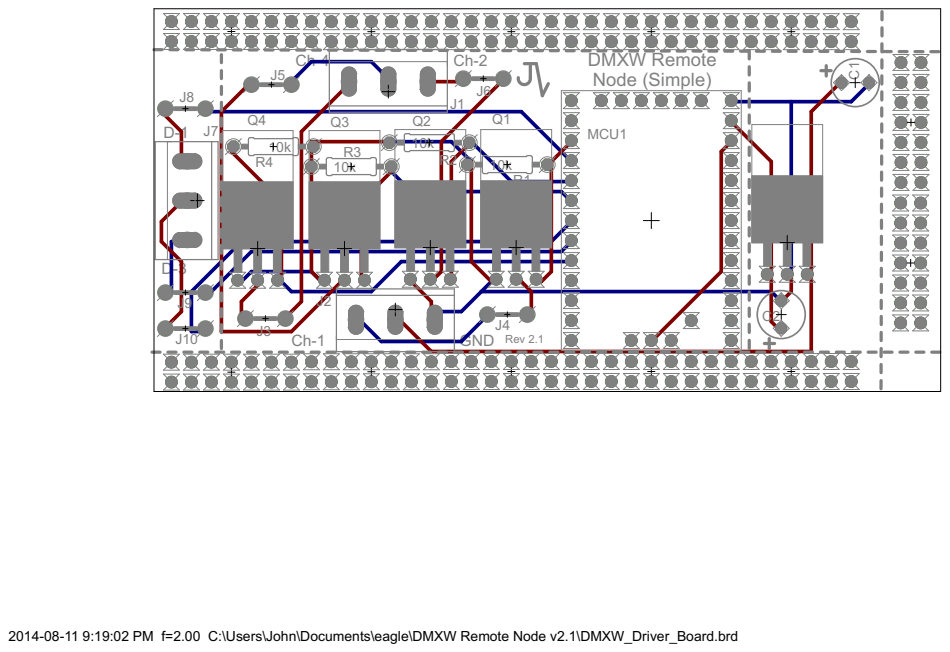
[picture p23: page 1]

MCU1

2014-08-11 9:19:02 PM f=2.00 C:\Users\John\Documents\eagle\DMXW Remote Node v2.1\DMXW_Driver_Board.brd

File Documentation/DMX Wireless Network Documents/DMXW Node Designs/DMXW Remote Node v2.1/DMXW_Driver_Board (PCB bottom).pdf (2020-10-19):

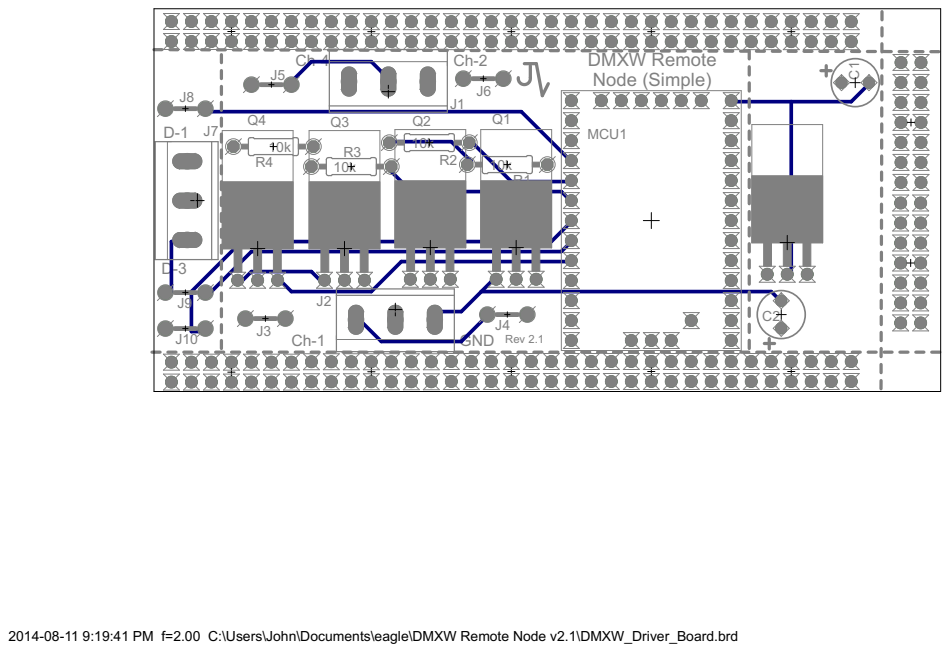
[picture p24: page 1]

2014-08-11 9:19:41 PM f=2.00 C:\Users\John\Documents\eagle\DMXW Remote Node v2.1\DMXW_Driver_Board.brd

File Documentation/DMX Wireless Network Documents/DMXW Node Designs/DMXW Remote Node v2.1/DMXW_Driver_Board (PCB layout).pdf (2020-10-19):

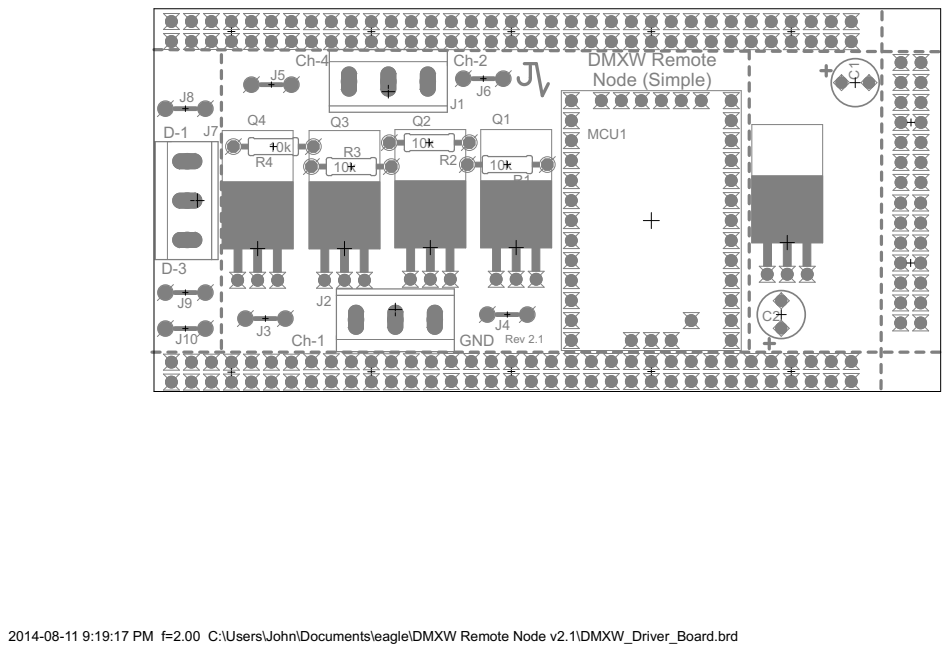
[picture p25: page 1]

2014-08-11 9:19:17 PM f=2.00 C:\Users\John\Documents\eagle\DMXW Remote Node v2.1\DMXW_Driver_Board.brd

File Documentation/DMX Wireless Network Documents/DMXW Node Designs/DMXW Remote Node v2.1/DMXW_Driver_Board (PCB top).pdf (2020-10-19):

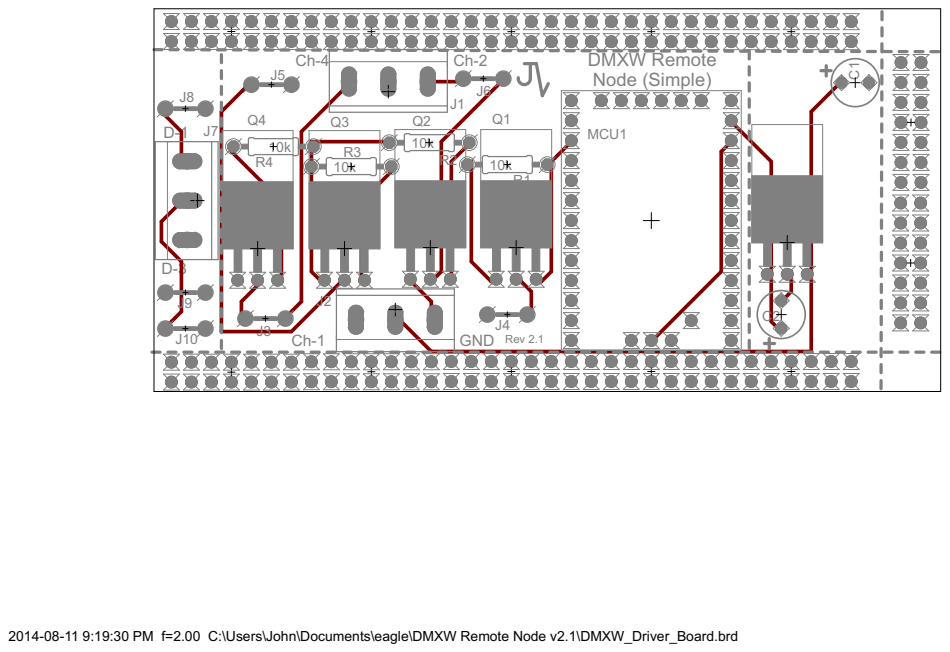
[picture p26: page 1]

2014-08-11 9:19:30 PM f=2.00 C:\Users\John\Documents\eagle\DMXW Remote Node v2.1\DMXW_Driver_Board.brd

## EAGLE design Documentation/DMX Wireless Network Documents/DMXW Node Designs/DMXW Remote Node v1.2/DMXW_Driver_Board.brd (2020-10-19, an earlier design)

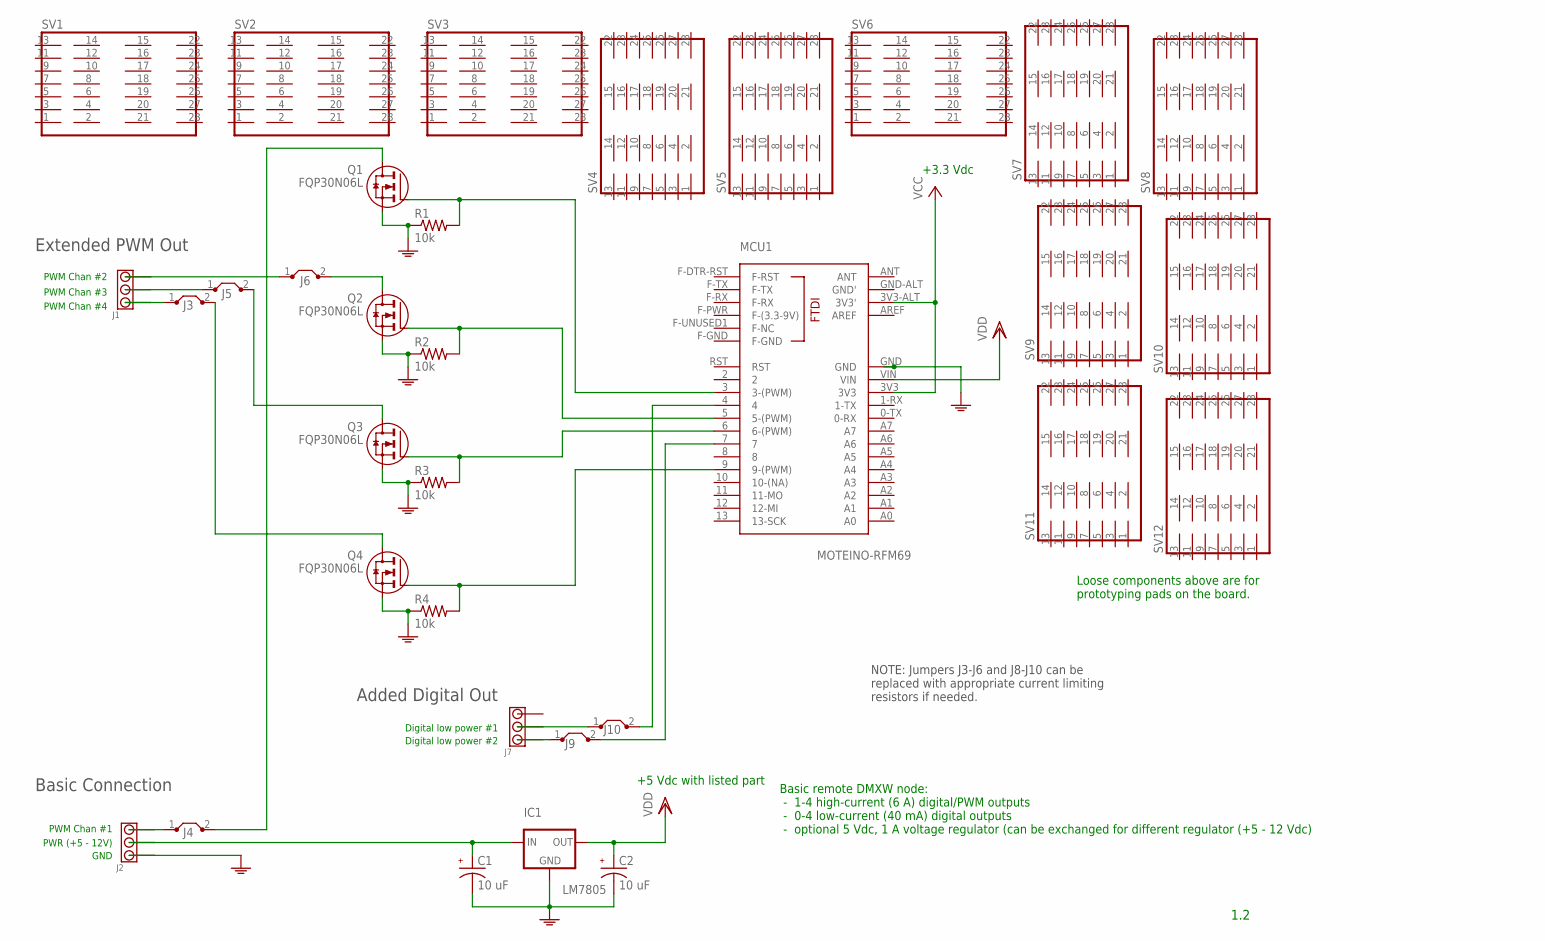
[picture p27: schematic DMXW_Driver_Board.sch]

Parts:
C1, C2: 10 uF; RADIAL-CANISTER
IC1: LM7805; TO-220
J1, J2, J7: TERMINAL-BLOCK-3; W237-103
J3, J4, J5, J6, J9, J10: J5MM; 05
MCU1: MOTEINO-RFM69; MOTEINO
Q1, Q2, Q3, Q4: FQP30N06L; TO-220
R1, R2, R3, R4: 10k; 0207/10
SV1, SV2, SV3, SV4, SV5, SV6, SV7, SV8, SV9, SV10, SV11, SV12: 14P

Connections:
GND: C1.-, C2.-, IC1.PIN2 (GND), J2.3, MCU1.GND, Q1.PIN3 (S), Q2.PIN3 (S), Q3.PIN3 (S), Q4.PIN3 (S), R1.1, R2.1, R3.1, R4.1
unnamed: MCU1.5 (5-(PWM)), Q2.PIN1 (G), R2.2
unnamed: J1.1, J6.1
unnamed: J1.2, J5.1
unnamed: J6.2, Q2.PIN2 (D)
unnamed: C1.+, IC1.PIN1 (IN), J2.2
unnamed: MCU1.6 (6-(PWM)), Q3.PIN1 (G), R3.2
unnamed: J5.2, Q3.PIN2 (D)
unnamed: MCU1.9 (9-(PWM)), Q4.PIN1 (G), R4.2
unnamed: J3.2, Q4.PIN2 (D)
unnamed: J10.2, MCU1.4
unnamed: MCU1.3 (3-(PWM)), Q1.PIN1 (G), R1.2
unnamed: J4.2, Q1.PIN2 (D)
unnamed: J9.2, MCU1.7
unnamed: J7.2, J10.1
unnamed: J2.1, J4.1
unnamed: J1.3, J3.1
unnamed: J7.3, J9.1
VCC: MCU1.3V3, MCU1.3V3-ALT (3V3')
VDD: C2.+, IC1.PIN3 (OUT), MCU1.VIN

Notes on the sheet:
PWR (+5 - 12V)
GND
PWM Chan #1
PWM Chan #4
PWM Chan #3
PWM Chan #2
Digital low power #2
Digital low power #1
1.2
+3.3 Vdc
Basic remote DMXW node: - 1-4 high-current (6 A) digital/PWM outputs - 0-4 low-current (40 mA) digital outputs - optional 5 Vdc, 1 A voltage regulator (can be exchanged for different regulator (+5 - 12 Vdc)
Basic Connection
Extended PWM Out
Added Digital Out
+5 Vdc with listed part
NOTE: Jumpers J3-J6 and J8-J10 can be replaced with appropriate current limiting resistors if needed.
Loose components above are for prototyping pads on the board.

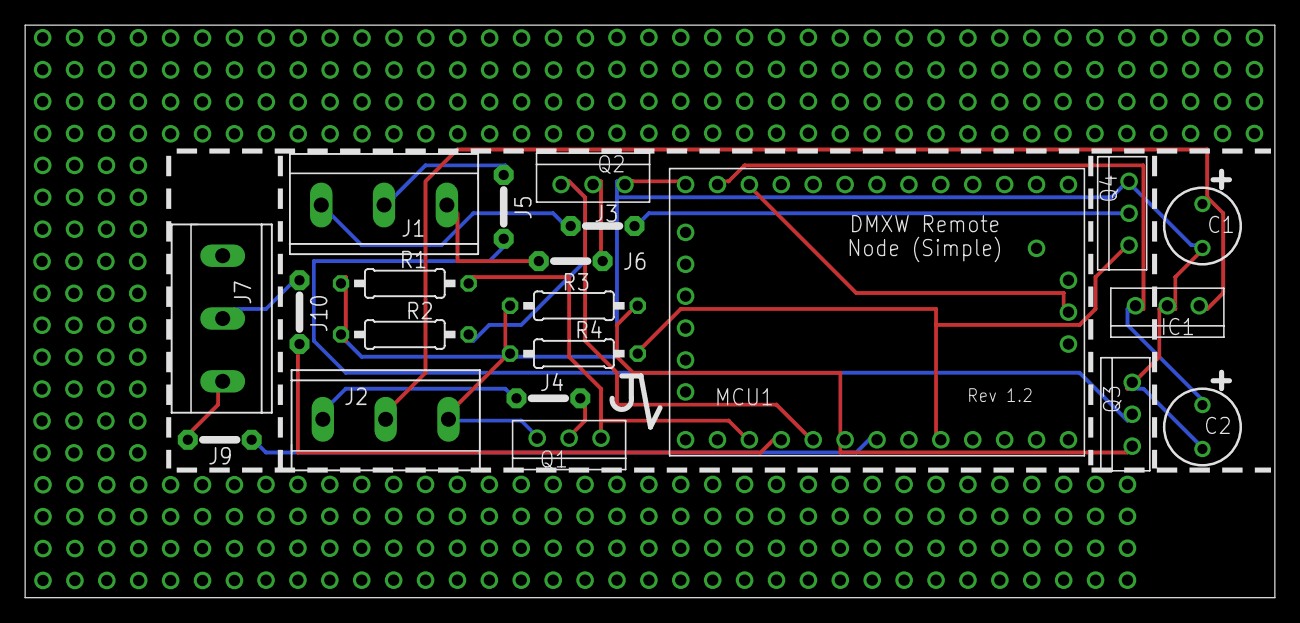
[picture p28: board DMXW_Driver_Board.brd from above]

Board: 2 copper layers, 99.5 x 45.6 mm, 33 parts (0 on the bottom side), 20 nets.

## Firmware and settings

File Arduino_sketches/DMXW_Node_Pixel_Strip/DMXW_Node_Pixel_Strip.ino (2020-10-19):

/******************************************************************************
 * DMXW_Node_Address_LED_Strip
 *
 * DMXW remote node for adressable LED strip.
 *
 * This sketches implements a DMX wireless remote node that interacts with the
 * DMS wireless gateway.
 *
 * All ports specify a lighting effect and effect parameters rather than
 * directly controlling individual output pins. Therefore, all ports are
 * assigned (by default) to output pin 4 which is used to control the
 * addressable LED strip. (The output pin can be changed to any pin in
 * the ranges 3-9, and 14-21.)
 *
 *         Port #  Pin # (Moteino)
 *         ------  ---------------
 *           1     4
 *           2     4
 *           3     4
 *           ...   ...
 *           16    4
 *
 * Port Definitions:
 * ----------------
 *
 *   Port 1  - Delay (in milliseconds; 0=LEDs off; 255=hold current settings)
 *   Port 2  - Effect:
 *               (Decade bands are used in order to ease manual config via
 *                potentiometers (e.g. on the DMXW Gateway))
 *               1: 10 - 19 = Colour Wipe
 *               2: 20 - 29 = Rainbow
 *               3: 30 - 39 = Rainbow Cycle
 *               4: 40 - 49 = Theatre Chase
 *               5: 50 - 59 = Theatre Chase Rainbow
 *               6: 60 - 69 = Water and Embers
 *               7: 70 - 79 = Twinkle
 *   Port 3   - Argument #1
 *   Port 4   - Argument #2
 *   Port 5   - Argument #3
 *   Port 6   - Argument #4
 *   Port 7   - Argument #5
 *   Port 7   - Argument #6
 *   (All other ports are undefined. DMX512 values assigned to those ports are
 *   ignored.)
 *
 * Effect Parameters: (All parameters are Uint8 values. [Delay] comes from
 *                     Port 1)
 * -----------------
 *   [x]<Effect>            ( Arg1, Arg2, ..., ArgN, [Delay] )
 *      -----------------   ---------------------------------------------
 *   [1]ColourWipe          ( Red, Green, Blue, [Delay] )
 *
 *   [2]Rainbow             ( [Delay] )
 *
 *   [3]RainbowCycle        ( [Delay] )
 *
 *   [4]TheatreChase        ( Red, Green, Blue, [Delay] )
 *
 *   [5]TheatreChaseRainbow ( [Delay] )
 *
 *   [6]WaterAndEmbers      ( RedLow, GreenLow, BlueLow,
 *                            RedHigh, GreenHigh, BlueHigh,
 *                            Depth, [Delay]
 *                          )
 *
 *   [7]Twinkle             ( Red, Green, Blue, Min[=1], Max[=100],
 *                            Simul[=5], Hold[=20]
 *                          )
 *                             Min = Min delay (x 10ms) before next twinkle
 *                             Max = Max delay (x 10ms) before next twinkle
 *                             Simul = Max # LEDs (triples) allowed to twinkle
 *                                     simultaneously
 *                             Hold = Duration (ms) for which twinkle is held
 *                             - defaulted values [=N] are used for arguments
 *                               with zero value
 *                             
 * When Delay is set to 255, other parameters can change without affecting
 * the current effect until Delay < 255.
 *
 *
 * Notes:
 * =====
 *   Special EEPROM memory locations:
 *      Address   Description
 *      -------   ----------------------------------
 *         0      Firmware Version
 *         1      Node ID (recorded in myNodeId)
 *         2      Mapping data validity (1=valid; 0=invalid)
 *         3      Addressable LED strip frequency (8 = 800 KHz, 4 = 400 KHz)
 *         4      Addressable LED strip LED wiring order (1 = GRB, 2 = RGB)
 *         5      Addressable LED strip length (# controlled tricolour
 *                  LED elements)
 *   Arduino Serial Monitor settings for console I/O:
 *     - 9600 baud
 *     - "Carriage return" as line ending
 *   LED strip wiring:
 *     The LED strips typically require a 5 Vdc signal voltage on the
 *     digital output control pin (ledStripCtrlPin). You should be able to get
 *     away with 3.3 Vdc (such as on a Moteino). (JVS: 3.3 Vdc does
 *     work for me.) The recommendation is, however, 5 Vdc. For 3.3 Vdc,
 *     a high speed 3.3 volt to 5 volt level conversion circuit is
 *     recommended. Also, it is suggested to follow the important Adafruit
 *     notes below.
 *
 * IMPORTANT [Adafruit note, assumes 5 Vdc digital output port voltages]:
 * =========
 *   To reduce NeoPixel burnout risk, add 1000 uF capacitor across pixel
 *   power leads, add 300 - 500 Ohm resistor on first pixel's data input
 *   and minimize distance between Arduino and first pixel. Avoid connecting
 *   on a live circuit...if you must, connect GND first.
 *
 * *** IMPORTANT ***
 * =================
 *   For some reason, when debug logging or console logging is enabled,
 *   it interferes with the control of the addressable LED strip (e.g.
 *   colours appear to be significantly dimmer than they should be).
 *   When operating normally, ensure that the flash is loaded with
 *   with a software version that is compiled without any of DEBUG_ON
 *   LOGGING_ON, or SERIAL_CMDS_ENABLED defined (comment out their #define
 *   statements). With SERIAL_CMDS_ENABLED defined, console input is still
 *   enabled and functions even though there is no feedback; the LEDs will
 *   glow noticeably dimmer. With LOGGING_ON defined, command feedback
 *   can be seen on the console; the LEDs will glow quite dimly.
 *
 *   When initially configuring a node--to set the nodeid, the LED strip
 *   length and, if necessary, change digital output pin used for
 *   controlling the strip--enable SERIAL_CMDS_ENABLED and LOGGING_ON.
 *   Once initial configuration has been completed, SAVEd, and tested,
 *   reflash the device with LOGGING_ON, SERIAL_CMDS_ENABLED, and
 *   DEBUG_ON disabled (comment out their #define statements).
 *
 *   FOLLOW-UP: The problem may be related to calling CheckRam() within
 *              setup().
 *
 * History
 * =======
 * Version  Date     Author         Description
 * -------  -------- -------------- -------------------------------------
 * 0.1      13-11-10 J.van Schouwen Initial creation.
 * 0.2      13-12-01 J.van Schouwen Complete working prototype of the DMXW
 *                                   node.
 * 0.21     14-08-10 J.van Schouwen Updated port mappings in the comments
 *                                   above.
 * 0.21A    14-12-16 J.van Schouwen Modified generic remote node for
 *                                   testing addressable LED strip
 * 1.0      16-01-07 J.van Schouwen Cleaning up code for addressable LED strip
 *                                   remote DMXW node.
 * 1.1      20-03-13 J.van Schouwen Updated from RFM69 library v1.0.0.
 *                                   (Prototype v1.1 released as Release_3.)
 *
 ******************************************************************************/

//Ruler
//345678901234567890123456789012345678901234567890123456789012345678901234567890

#include <RFM69.h>
#include <SPI.h>
#include "DMXWNet.h"
#include <avr/pgmspace.h>
#include <EEPROM.h>
#include <Adafruit_NeoPixel.h>

#define COPYRIGHT     "(C)2020, A.J. van Schouwen"
#define SW_VERSION_c  "1.1 (2020-03-13)"
#define FW_VERSION_c  7   // Increment (with wraparound) for new F/W;
                          //   clears EEPROM.

//#define DEBUG_ON            // Uncomment to turn off debug output to serial port.
#define LOGGING_ON          // Uncomment to turn off packet logging to serial port.
#define SERIAL_CMDS_ENABLED // Enables command line at serial port

#define PIN_LOCATE    9   // Pin number of digital port connected to
                          // onboard LED (for location purposes)
#define NEO_PIN       4   // Default digital pin for LED strip control
                          // (overidden by ledStripCtrlPin)

#define MAX_SERIAL_BUF_LEN  20
#define EEPROM_FW_ADDR             0
#define EEPROM_NODEID_ADDR         1
#define EEPROM_VALIDITY_ADDR       2
#define EEPROM_STRIP_CTRL_PIN      3
#define EEPROM_STRIP_FREQ_ADDR     4
#define EEPROM_STRIP_WIRING_ADDR   5
#define EEPROM_STRIP_LEN_ADDR      6
#define EEPROM_FIRST_OPEN_ADDR     7

#define SERIAL_BAUD                4800

#define DEL_CHAR                   0x7F  // ASCII Del character


// Macro for defining strings that are stored in flash (program) memory rather
// than in RAM. Arduino defines the non-descript F("string") syntax.
#define FLASH(x) F(x)

#ifdef DEBUG_ON
  #define dbgPrint(x)    Serial.print(x)
  #define dbgPrintln(x)  Serial.println(x)
#else
  #define dbgPrint(x)
  #define dbgPrintln(x)
#endif

#ifdef LOGGING_ON
  #define logPrint(x)    Serial.print(x)
  #define logPrintln(x)  Serial.println(x)
#else
  #define logPrint(x)
  #define logPrintln(x)
#endif


Adafruit_NeoPixel *strip;

// IMPORTANT [Adafruit note]: To reduce NeoPixel burnout risk, add 1000 uF
// capacitor across pixel power leads, add 300 - 500 Ohm resistor on first
// pixel's data input and minimize distance between Arduino and first pixel.
// Avoid connecting on a live circuit...if you must, connect GND first.


// Node ID.
// Must be unique for each node. Gateway is always 1.
// Range: 2 - 20  (0 = 'undefined')
Uint8   myNodeId = 0;  // Must be unique for each node 

RFM69   radio;
bool    promiscuousMode = true;  // sniff all packets on network iff true
Uint8   dstNodeId;
Uint8   srcNodeId;

bool    resetEeprom = false;
bool    handleInput = false;
bool    ackRequested = false;
bool    dataToSend = false;
bool    requestAck = true;
bool    saveMappings = false;
Uint8   currReadPos = 0;
Uint8   command = 0;
Uint8   buffer[RF69_MAX_DATA_LEN];
Uint8   ackBuf[1];
Uint8   bufSize = 0;
char    serialBuffer[MAX_SERIAL_BUF_LEN];
Uint8   serialBufSize = 0;
Uint8   serialPos = 0;
long    rxTime = 0;
long    ackTime = 0;
bool    nodeIdValid = false;
unsigned long rxCount = 0;
Uint8   resetCount;
Uint16  badAddr = 0;
long    nextFxTime = 0;
long    currentTime = 0;


// Port to I/O pin mapping
NodePortMapRecord_t portMap[MAX_PORTS] =
{
  //JVS: Pins are now disconnected from nodeMap[]--i.e. no direct DMXW control
  //     Control the LED strip parameters through the DMXW ports
  //     Below, the outPin assignments are the default (NEO_PIN); these
  //     get altered in EepromLoad().
  //
  //         conflict   is
  //{ outPin,  Port,  Analog, name}
    { NEO_PIN,   -1,   false, "Speed"  }, // Port 1 - Speed (0 = off)
    { NEO_PIN,   -1,   false, "Effect" }, // Port 2 - Effect:
                                          //           1 = Colour Wipe
                                          //           2 = Rainbow
                                          //           3 = Rainbow Cycle
                                          //           4 = Theatre Chase
                                          //           5 = Theatre Chase Rainbow
                                          //           6 = Water Effect
    { NEO_PIN,   -1,   false, "Arg #1" }, // Port 3   - Argument #1
    { NEO_PIN,   -1,   false, "Arg #2" }, // Port 4   - Argument #2
    { NEO_PIN,   -1,   false, "Arg #3" }, // Port 5   - Argument #3
    { NEO_PIN,   -1,   false, "Arg #4" }, // Port 6   - Argument #4
    { NEO_PIN,   -1,   false, "Arg #5" }, // Port 7   - Argument #5
    { NEO_PIN,   -1,   false, "Arg #6" }, // Port 8   - Argument #6
    { NEO_PIN,   -1,   false, "Arg #7" }, // Port 9   - Argument #7
    { NEO_PIN,   -1,   false, " -"     }, // Port 10
    { NEO_PIN,   -1,   false, " -"     }, // Port 11
    { NEO_PIN,   -1,   false, " -"     }, // Port 12
    { NEO_PIN,   -1,   false, " -"     }, // Port 13
    { NEO_PIN,   -1,   false, " -"     }, // Port 14
    { NEO_PIN,   -1,   false, " -"     }, // Port 15
    { NEO_PIN,   -1,   false, " -"     }, // Port 16
};

const Uint8 stripLastPortNum = 9; // Last port # actually used above


// LED strip parameters
Uint8   stripDelay, stripEffect;
Uint8   stripArg1, stripArg2, stripArg3, stripArg4;
Uint8   stripArg5, stripArg6, stripArg7;
Uint8   oldStripEffect = 0;
bool    stripParamChange = false;
bool    newEffect = false;
bool    disableEffects = false;
Uint8   ledStripFlags;

// LED strip configuration settings
Int8   ledStripCtrlPin;  // Configured output pin for LED strip control
                         //   (Default is NEO_PIN.)
                         
Uint8   ledStripFreq;    // Configured LED strip frequency
  //   NEO_KHZ800  800 KHz bitstream (most NeoPixel products w/WS2812 LEDs)
  //   NEO_KHZ400  400 KHz (classic 'v1' (not v2) FLORA pixels, WS2811 drivers)

Uint8   ledStripWiring;  // Configured LED strip colour wiring order
  //   NEO_GRB     Pixels are wired for GRB bitstream (most NeoPixel products)
  //   NEO_RGB     Pixels are wired for RGB bitstream (v1 FLORA pixels, not v2)
  //     JVS: On the 12V strip that I have, change the colour order in functions
  //          calls from R/G/B to R/B/G

Uint8   ledStripLen;     // # of LED triplets (12V strip has 3 tricolour
                         //   LEDs per WS2811 driver). So the LEDs, in this
                         //   configuration, aren't really individually
                         //   addressable.
                        

// Array, indexed by port # (0 = port #1), mapping port # to DMXW channel #.
Uint8 portToDmxwMap[MAX_PORTS];



// List of defined ports indexed by DMXW channel # (-1 = not used; 0 = chan #1)
DmxwNodeMapRecord_t nodeMap[MAX_DMXW_CHANS];

Uint8 node;

Int8 blinkState = 0;  // 0 = disabled; 1 = on; -1 = off
long blinkTime = 0;
long lastTime = 0;



void EepromLoad()
{
  int addr;
  bool dataIsValid;

  dataIsValid = EEPROM.read(EEPROM_VALIDITY_ADDR);
  ledStripCtrlPin = NEO_PIN;

  if (!dataIsValid)
    return;

  ledStripCtrlPin = EEPROM.read(EEPROM_STRIP_CTRL_PIN);
  ledStripFreq    = EEPROM.read(EEPROM_STRIP_FREQ_ADDR);
  ledStripWiring  = EEPROM.read(EEPROM_STRIP_WIRING_ADDR);
  ledStripLen     = EEPROM.read(EEPROM_STRIP_LEN_ADDR);
      
  for (Uint8 i = 0; i < MAX_PORTS; i++)
  {
    portMap[i].outPin = ledStripCtrlPin;
  }
  
  addr = EEPROM_FIRST_OPEN_ADDR;
  for (Uint8 i = 0; i < MAX_DMXW_CHANS; i++)
  {
    nodeMap[i].port          = EEPROM.read(addr++);
    nodeMap[i].isLogarithmic = EEPROM.read(addr++);
    //nodeMap[i].value       = EEPROM.read(addr++); // Don't store the value
    nodeMap[i].value         = 0;
  }
  
  for (Uint8 i = 0; i < MAX_PORTS; i++)
  {
    portToDmxwMap[i] = EEPROM.read(addr++);
  }
  pinMode(ledStripCtrlPin, OUTPUT);
}

void EepromSave()
{
  const Uint8 dataIsValid = 1;
  int addr;

  EEPROM.write(EEPROM_VALIDITY_ADDR,     dataIsValid);
  EEPROM.write(EEPROM_STRIP_CTRL_PIN,    ledStripCtrlPin);
  EEPROM.write(EEPROM_STRIP_FREQ_ADDR,   ledStripFreq);
  EEPROM.write(EEPROM_STRIP_WIRING_ADDR, ledStripWiring);
  EEPROM.write(EEPROM_STRIP_LEN_ADDR,    ledStripLen);

  addr = EEPROM_FIRST_OPEN_ADDR;
  for (Uint8 i = 0; i < MAX_DMXW_CHANS; i++)
  {
    EEPROM.write(addr++, nodeMap[i].port);
    EEPROM.write(addr++, nodeMap[i].isLogarithmic);
    //EEPROM.write(addr++, nodeMap[i].value); // Don't store the value
  }
  for (Uint8 i = 0; i < MAX_PORTS; i++)
  {
    EEPROM.write(addr++, portToDmxwMap[i]);
  }
}
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
void loop()
{
  handleInput = false;
  bufSize = 0;
  dataToSend = false;
  requestAck = true;
  ackBuf[0] = ACK_ERR;
  
  // Handle incoming messages.
  if (radio.receiveDone())
  {
    // Determine if the message is aimed at us.
    dstNodeId = radio.TARGETID;
    srcNodeId = radio.SENDERID;
    // Handle the RX msg if it's intended for me
    if ( ( (dstNodeId == myNodeId) && (dstNodeId > NODEID_UNDEF) ) ||
         ( (dstNodeId == BROADCASTID) && (srcNodeId == GATEWAYID) ) )
    {
      if ( (radio.DATA[0] == srcNodeId) && (radio.DATA[1] == dstNodeId))
      {
        bufSize = radio.DATALEN - 2;
        if (bufSize <= (MAX_DMXW_CHANS + 1))
        {
          handleInput = true;
          ackRequested = radio.ACK_REQUESTED;
          memcpy(buffer, (const void *)&radio.DATA[2], bufSize);
        }
        else
        {
          logPrintln(FLASH("*** RX invalid pkt length; dropped"));
        }
      }
      else
      {
//JVS??
        bufSize = radio.DATALEN - 2;
        memcpy(buffer, (const void *)&radio.DATA[2], bufSize);
//
        logPrint(FLASH("*** RX corrupt pkt; dropped. ["));
        for (int i = 0; i < bufSize; i++)
        {
          logPrint(buffer[i]);
          logPrint(FLASH("  "));
        }
        logPrintln(FLASH("]"));
      }
    }
    else
    {
      badAddr++;
      dbgPrint(FLASH(" ... ignored (pkt not for me). Src:"));
      dbgPrint(srcNodeId);
      dbgPrint(FLASH(" Dst:"));
      dbgPrint(dstNodeId);
      dbgPrintln(FLASH(")"));
//JVS??  vvv
/*        bufSize = radio.DATALEN - 2;
        memcpy(buffer, (const void *)&radio.DATA[2], 30);
*/
      logPrintln(FLASH(" ... ignored (pkt not for me)"));
/*
      logPrint(srcNodeId);
      logPrint(FLASH(" Dst:"));
      logPrint(dstNodeId);
      logPrint(FLASH("  #Bad:"));
      logPrint(badAddr);
      logPrint(FLASH(")  ["));
for (int i = 0; i < 30; i++)
{
  logPrint(buffer[i]);
  logPrint("  ");
}
logPrintln("]");
*/
//JVS??  ^^^
    }
    
    dbgPrint(FLASH("RX  Src["));
    dbgPrint(radio.SENDERID);
    dbgPrint(FLASH("]  Dst["));
    dbgPrint(radio.TARGETID);
    dbgPrint(FLASH("]  Size["));
    dbgPrint(radio.DATALEN);
    dbgPrint(FLASH("]  "));
    
    /*Serial.print(FLASH(" DATA["));
    for (Uint8 i = 0; i < radio.DATALEN; i++)
    {
      Serial.print(radio.DATA[i]); Serial.print(" ");
    }
    Serial.print("]  ");
    */
  
    if (handleInput)
    {
      rxTime = millis();
      currReadPos = 0;
      command = buffer[currReadPos++];

      dbgPrint(FLASH("Cmd["));
      printCommand(command);
      dbgPrint("] ");
      rxCount++;
      ackBuf[0] = (Uint8) handleNetRxMessage(command);

      dbgPrint(FLASH("  Result["));
      printAckResult(ackBuf[0]);
      dbgPrintln("]");
      if (ackRequested)
      {
        radio.sendACK(ackBuf, 1);
        dbgPrint(FLASH("ACK sent["));
        dbgPrint(millis() - rxTime);
        dbgPrintln("]");
      }
    }
  }
  
  #ifdef SERIAL_CMDS_ENABLED
    getSerialCommand();
  #endif

  if (saveMappings)
  {
    saveMappings = false;
    EepromSave();
  }
  
  if (dataToSend)
  {
//JVS??
    if ((bufSize + 2) <= RF69_MAX_DATA_LEN)
    {
      ackTime = millis();
      memmove(&buffer[2], buffer, bufSize);
      bufSize += 2;
      buffer[0] = myNodeId;
      buffer[1] = node;
      ackBuf[0] = sendBuffer(node, buffer, bufSize, requestAck);
      dbgPrint(FLASH(" RxAck["));
      dbgPrint(millis() - ackTime);
      dbgPrint("]");
      dbgPrint(FLASH("  Result["));
      printAckResult(ackBuf[0]);
      dbgPrintln("]");
    }
  }
  
//JVS??
/*
  if (handleInput && (rxCount % 1000) == 0)
  {
    logPrint(FLASH("rxCount:"));
    logPrint(rxCount);
    logPrint(FLASH("\t"));
    CheckRam();
  }
*/

  lastTime = millis();
  if (blinkState)
  {
    if ((lastTime - blinkTime) > 500)
    {
      blinkTime = lastTime;
      blinkState = -blinkState;
      if (blinkState == 1)
        digitalWrite(PIN_LOCATE, HIGH);
      else
        digitalWrite(PIN_LOCATE, LOW);
    }
  }

  /* Override parameter changes if Delay is 255 */
  if (nodeMap[portToDmxwMap[0]-1].value == 255)
  {
    stripParamChange = false;
  }
  
  if (stripParamChange)
  {
    Uint8 tmpDmxwChan;
    
    tmpDmxwChan = portToDmxwMap[0];  // Port 1 --> DMXW chan #
    if (tmpDmxwChan == 0)
      stripDelay = 0;
    else
      stripDelay = nodeMap[tmpDmxwChan-1].value;
      
    tmpDmxwChan = portToDmxwMap[1];
    if (tmpDmxwChan == 0)
      stripEffect = 0;
    else
      stripEffect = nodeMap[tmpDmxwChan-1].value / 10;
      
    tmpDmxwChan = portToDmxwMap[2];
    if (tmpDmxwChan == 0)
      stripArg1 = 0;
    else
      stripArg1 = nodeMap[tmpDmxwChan-1].value;
      
    tmpDmxwChan = portToDmxwMap[3];
    if (tmpDmxwChan == 0)
      stripArg2 = 0;
    else
      stripArg2 = nodeMap[tmpDmxwChan-1].value;
      
    tmpDmxwChan = portToDmxwMap[4];
    if (tmpDmxwChan == 0)
      stripArg3 = 0;
    else
      stripArg3 = nodeMap[tmpDmxwChan-1].value;

    tmpDmxwChan = portToDmxwMap[5];
    if (tmpDmxwChan == 0)
      stripArg4 = 0;
    else
      stripArg4 = nodeMap[tmpDmxwChan-1].value;

    tmpDmxwChan = portToDmxwMap[6];
    if (tmpDmxwChan == 0)
      stripArg5 = 0;
    else
      stripArg5 = nodeMap[tmpDmxwChan-1].value;

    tmpDmxwChan = portToDmxwMap[7];
    if (tmpDmxwChan == 0)
      stripArg6 = 0;
    else
      stripArg6 = nodeMap[tmpDmxwChan-1].value;

    tmpDmxwChan = portToDmxwMap[8];
    if (tmpDmxwChan == 0)
      stripArg7 = 0;
    else
      stripArg7 = nodeMap[tmpDmxwChan-1].value;

 
    switch (stripEffect)
    {
      case 1: logPrint("Colour Wipe");            break;
      case 2: logPrint("Rainbow");                break;
      case 3: logPrint("Rainbow Cycle");          break;
      case 4: logPrint("Theatre Chase");          break;
      case 5: logPrint("Theatre Chase Rainbow");  break;
      case 6: logPrint("Water and Embers");       break;
      case 7: logPrint("Twinkle");                break;
      case 8: logPrint("Ember Effect");           break;
      default:
        logPrint("<unknown effect (");
        logPrint(stripEffect);
        logPrint (")>");
    }
    logPrint(": Delay="); logPrint(stripDelay);
    logPrint("  (");
    logPrint(stripArg1);
    logPrint(", ");
    logPrint(stripArg2);
    logPrint(", ");
    logPrint(stripArg3);
    logPrint(", ");
    logPrint(stripArg4);
    logPrint(", ");
    logPrint(stripArg5);
    logPrint(", ");
    logPrint(stripArg6);
    logPrint(", ");
    logPrint(stripArg7);
    logPrintln(")");
    
    if (stripEffect != oldStripEffect)
    {
      oldStripEffect = stripEffect;
      newEffect = true;
    }
    else
    {
      if ( ((stripEffect == 1) || (stripEffect == 7))
           && stripParamChange)
      {
        newEffect = true;
      }
    }
    stripParamChange = false;
  }
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

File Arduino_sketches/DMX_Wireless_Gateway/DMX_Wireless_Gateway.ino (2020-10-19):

/******************************************************************************
 * DMX_Wireless_Gateway
 *
 * This sketches implements a DMX wireless gateway controller that controls
 * nodes containing RFM69 radio transceivers. A DMX controller has a wired
 * connection to the gateway unit. This gateway can be configured to
 * respond to up to 20 DMX channels and can be configured to communicate
 * with up to 20 wireless RFM69 client nodes. For each configured DMX channel
 * the gateway relays channel values to the appropriate (node, port) pair.
 * Each RFM69 client node has available up to 10 local digital output port, of
 * which up to 6 could support PWM (psuedo analog) output.
 *
 * Each client also has available up to 10 digital input ports and up to 6
 * analog input ports (which are independent of the digital input ports).
 * Input values can be transmitted back to the gateway for monitoring purposes.
 *
 * NOTES on channel, node, and port numbering
 *   - DMX Wireless Gateway numbers DMX channels from 1 - 512. (An internal
 *     channel number of 0 indicates 'undefined/unassigned'.)
 *   - DMX wirless network gateway and nodes are numbered from 1 - 21 (and 255)
 *     with the gateway being node #1. Messages sent to node #255 are broadcasts.
 *   - Port numbers on nodes are numbered 1 - 10 (for digital I/O) and
 *     11 - 16 (for psuedo analog outputs (PWM) and analog inputs).
 *   - terminal emulator (e.g. Linum minicom) settings for console I/O:
 *         - 9600 baud 8 data bits, no parity, 1 stop bit
 *         - enable local echo
 *         - no hardware flow control; software flow control
 *
 * The gateway is also capable of local console control of the 20
 * (node, port) outputs via:
 *    - a single 2-axis analog joystick
 *    - 2 potentiometers
 *    - 4 pushbuttons
 * enabling local control of up to 4 analog (node, port) pairs and
 * 4 digital (node, port) pairs.
 *
 * DMX control and local control are mutually exclusive. There is a switch
 * on the gateway for selecting between DMX and console control.
 *
 * Notes:
 * =====
 *   Special EEPROM memory locations:
 *      Address   Description
 *      -------   ----------------------------------
 *         0      Firmware Version
 *         1      Number of dmxMap[] entries stored.
 *
 *   *** Need to import <SoftwareSerial.h> and translate all print statements
 *       from Serial.print...   to mySerial.print... as the built-in Serial
 *       library is incompatible with the DMXSerial library. This also implies
 *       that console I/O will have to go thru a separate serial port. (Need
 *       to reserve a couple of digital pins for that.)
 *       The DMX_Wireless_Node is not affected because it doesn't use
 *       the DMXSerial library.
 *
 * Console Controls:
 * ================
 *   Control              Pin
 *   ----------------     ---
 *   Joystick x-axis      A0
 *   Joystick y-axis      A1
 *   Potentiometers       A2, A3
 *   Pushbuttons          D3, D4, D5, D6
 *
 * History
 * =======
 * Version  Date     Author         Description
 * -------  -------- -------------- -------------------------------------
 * 0.1      13-11-09 J.van Schouwen Initial creation.
 * 0.2      13-12-01 J.van Schouwen Initial prototype that is able to
 *                                   distribute data to 20-60 DMXW wireless
 *                                   nodes, plus console controls. It doesn't
 *                                   yet actually handle DMX-512 input.
 * 1.0      14-03-06 J.van Schouwen First release.
 * 1.1      15-11-02 J.van Schouwen Second (minor) release. (No firmware
 *                                   up-version.) Fix bug in command line
 *                                   editing. Fix display of version info.
 *          20-03-30 J.van Schouwen (Release_2 (prototype v1.1) re-released as
 *                                   Release_3 to maintain a complete release
 *                                   lineup.)
 *
 ******************************************************************************/

//Ruler
//345678901234567890123456789012345678901234567890123456789012345678901234567890

#include <SoftwareSerial.h>
#include <DMXSerial.h>
#include <RFM69_DMX.h>
#include <SPI.h>
#include "DMXWNet.h"
#include <avr/pgmspace.h>
#include <EEPROM.h>

#define COPYRIGHT       "(C)2015, A.J. van Schouwen"
#define SW_VERSION_c    "1.1 (2015-11-02)"
#define FW_VERSION_c    9   // Increment (with wraparound) for new F/W;
                            //   clears EEPROM.

//#define DEBUG_ON            // Uncomment to turn off debug output to serial port.
#define LOGGING_ON          // Uncomment to turn off packet logging to serial port.

#define PIN_LOCATE      9   // Pin number of digital port connected to
                            // onboard LED (for location purposes)
#define MAX_SERIAL_BUF_LEN  20
#define EEPROM_FW_ADDR             0
#define EEPROM_NUMDMXNODES_ADDR    1
#define EEPROM_FIRST_OPEN_ADDR     2
#define INVALID_MAP_INDEX  (MAX_DMXW_CHANS + 1)

#define SERIAL_BAUD            9600

#define DEL_CHAR               0x7F  // ASCII Del character

#define NUM_BUTTONS            5  // Includes joystick button
#define NUM_POTS               2

/*** Digital input pins ***/
// Console buttons
#define BUTTON1_PIN            6  // Button #1
#define BUTTON2_PIN            9  // Button #2
#define BUTTON3_PIN           14  // Button #3
#define BUTTON4_PIN           15  // Button #4
#define BUTTON5_PIN           16  // Button #5 (joystick button)

#define CONFIG_ENABLED_PIN     4
#define CONSOLE_ENABLED_PIN   17

/*** Digital output pins ***/
#define DMXW_ACTIVITY_LED      3
#define DMX512_ACTIVITY_LED    5

/*** Analog input pins ***/
// Console knobs
#define JOY_X_PIN              5  // Joystick X axis
#define JOY_Y_PIN              4  // Joystick Y axis
#define POT1_PIN               6  // Potentiometer #1
#define POT2_PIN               7  // Potentiometer #2

#define CONFIG_RX              7  // Console Serial RX port
#define CONFIG_TX              8  // Console Serial TX port


// A 45 ms TX delay equates to a 22 Hz DMXW refresh rate. A DMX-512
// network running the full 512 channels has a refresh rate of 44Hz.
// So we're running at half the slowest refresh rate.
// (Note that a DMX-512 network running fewer channels can refresh
// much more quickly. The minimum frame time is 1196 microsecs (or 836 Hz),
// which can be achieved with at most 24 channel slots.)
#define DMXW_TX_DELAY            35  // milliseconds
#define DMX_SUSPEND_DURATION   2000  // milliseconds

#define DMXW_TEST_MODE            1


// Macro for defining strings that are stored in flash (program) memory rather
// than in RAM. Arduino defines the non-descript F("string") syntax.
#define FLASH(x) F(x)

#ifdef DEBUG_ON
  #define dbgPrint(x)    consSerial.print(x)
  #define dbgPrintln(x)  consSerial.println(x)
  #define DEBUGGING  1
#else
  #define dbgPrint(x)
  #define dbgPrintln(x)
  #define DEBUGGING  0
#endif
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
